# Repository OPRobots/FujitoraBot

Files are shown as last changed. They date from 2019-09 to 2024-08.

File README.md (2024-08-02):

# FujitoraBot
Robot siguelineas MAS RAPIDO DE ESPAÑA!! con motores brushless, succión centrifuga y STM32F4

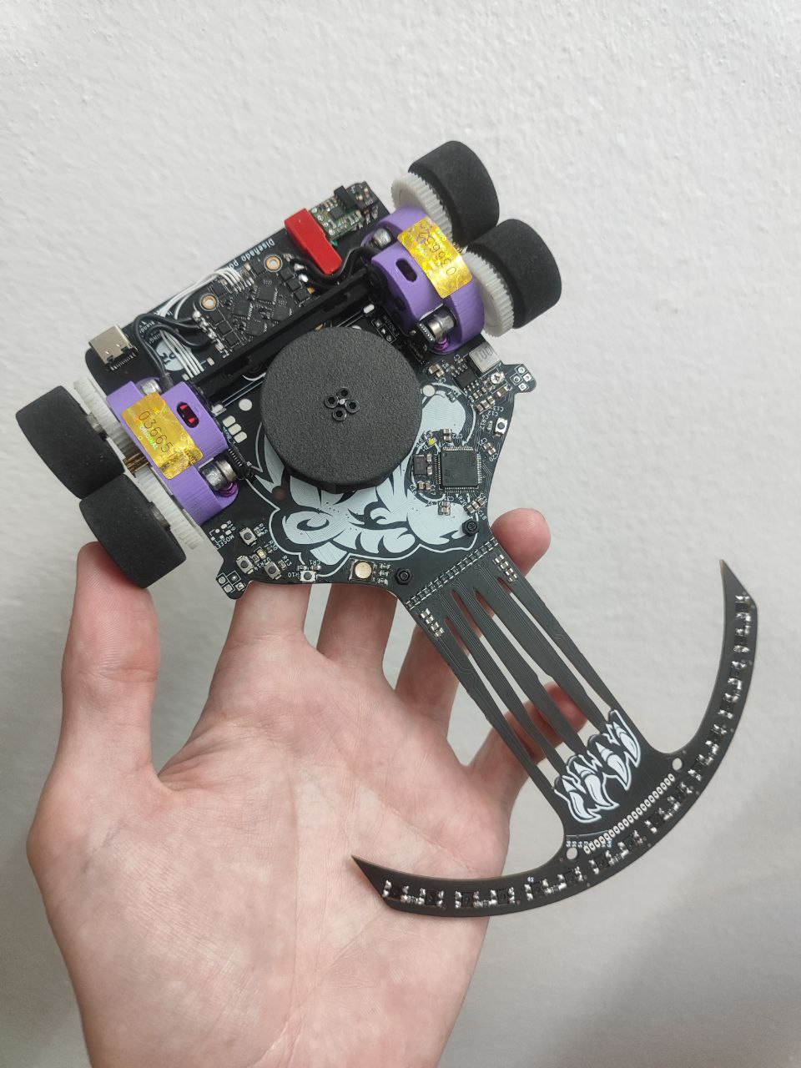
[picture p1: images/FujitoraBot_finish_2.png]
FujitoraBot


## Hardware
- STM32F405RGT6
- ESC 4in1 BlHeli 14A
- 2x Motores Brushless 1306 2700KVs
- 1x Motor brushless 1104 4000KVs (succión)
- DIP Switch 2p SMD
- LiPo 3S 380 mAh
- 16x sensores QRE1113
- Ruedas Scaleauto Procomp 1
- Chasis de PCB con soportes de motores y ventilador en Nylon PA12 SLS

## Software
- Programado con VSCode y PlatformIO con LibOpenCM3
- Disponibles programas de competición

### Versión Robotracer
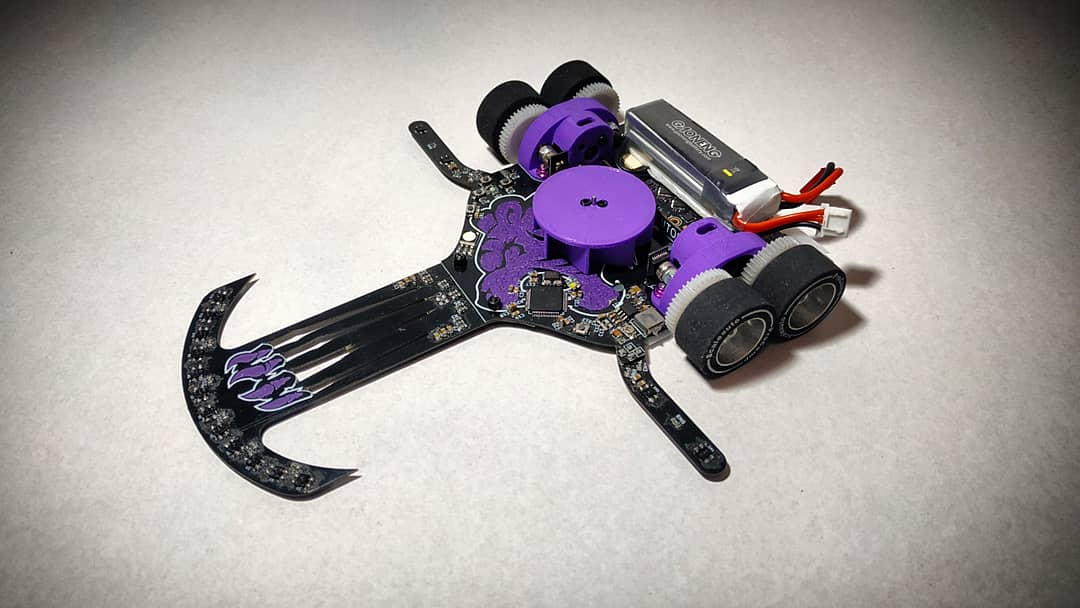
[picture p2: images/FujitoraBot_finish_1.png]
FujitoraBot


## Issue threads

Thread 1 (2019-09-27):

Modos de debug

20leunam, 2019-09-27:
Al seleccionar cada uno de los siguientes modos de debug el led RGB se iluminará con el color correspondiente al modo. Al igual que el menú de velocidad y succión.
- Sensores Raw (cian)
- Sensores calibrados (verde suave)
- Posición de linea (verde)
- Debug motores (amarillo suave)
- Encoders (amarillo)
- Entradas digitales (rojo suave)
- ... (rojo)
- ... (morado suave)
- Fiesta de leds (morado)
- Demostración succión (ultra-instinto)

**Cuando se selecciona un modo de debug se arranca y para con el boton "Start" y fadeará el color correspondiente mientras esté activado. (excepto en "Fiesta de leds" creo)

20leunam, 2019-09-27:
En el tema de analizar si los encoders fallan sería interesante utilizar el index y el numero de pulsos por vuelta para determinar si están dando problemas o no.
En caso de detectar irregularidad en los pulsos de los encoders entre paso y paso del index quizas se podria poner en "alarma" el robot para notificarnoslo, y que pasase automaticamente a de m/s a pwm

robotaleh, 2019-09-28:
> En el tema de analizar si los encoders fallan sería interesante utilizar el index y el numero de pulsos por vuelta para determinar si están dando problemas o no.
> En caso de detectar irregularidad en los pulsos de los encoders entre paso y paso del index quizas se podria poner en "alarma" el robot para notificarnoslo, y que pasase automaticamente a de m/s a pwm

Esto mejor se pasa a un "pending" a parte.

Closed 2019-09-28.

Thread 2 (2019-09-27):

Metodo de selección de modo

20leunam, 2019-09-27:
Con la pulsación por flanco positivo del botón "Enter" se navegará por los siguientes modos:
- Velocidad (parpadeo rápido 50ms)
- Succión (parpadeo medio 200ms)
- Debug (fijo)

** Al cambiar de modo se encenderá el color correspondiente a la configuración que tiene asignada en ese momento durante 250ms

Closed 2019-09-28.

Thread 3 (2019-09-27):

PID a 1ms

20leunam, 2019-09-27:
Cambiar la velocidad de PID a 1ms y que la asignación de velocidad sea inmediatamente despues del calculo del PID, siendo esta, por tanto, asignada también cada 1ms.

**Intentar hacer funcionar los brushless con OneShot 42 (12khz) aunque no coincidan los prescalers

robotaleh, 2019-09-29:
> **Intentar hacer funcionar los brushless con OneShot 42 (12khz) aunque no coincidan los prescalers

Al jugar con los prescalers se consiguen frecuencias de 11,7kHz o 12,6kHz. Con la primera los ESC no se inician y con la segunda arrancan sin control a máxima velocidad; en un futuro si eso se vuelve a intentar.

Closed 2019-09-29.

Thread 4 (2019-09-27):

Sistema de setup

20leunam, 2019-09-27:
Como se deberá comportar el robot en cuanto se encienda:
- Encender robot
- Inicializar timers, relojes, motores, etc.
- Comprobar el estado de los Switches
- Calibrar (en función de los switches calibrará de una u otra forma)
- Atender a los botones de configuración.

robotaleh, 2019-09-29:
Esto ya está listo al atender las issues #1 y #2

Closed 2019-09-29.

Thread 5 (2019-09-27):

The BIG Filtro

20leunam, 2019-09-27:
The BIG Filtro

Realizar un filtro anti saltos sobre la pista que consiste en:
Cuando todos, o la gran mayoría de los sensores valen similar (todos detectando o todos sin detectar) y el último sensor detectando, no es el del extremo correspondiente, mantener el error anterior.

Otra forma de interpretarlo podría ser:
Si la posición del robot es la máxima o la mínima, y la posición anterior no estaba cerca de la máxima o la mínima (según corresponda) mantener la posición anterior.

Closed 2019-09-29.

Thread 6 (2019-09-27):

The BIGGER Filtro

20leunam, 2019-09-27:
The BIGGER Filtro

Realizar un filtro de marcas en el array principal, de tal forma que solo haga caso a la linea central e ignore los sensores que están alejados de la linea dado que se entiende que la información que aporten es irrelevante.

**Teóricamente con este filtro se deberia autoresolverse la issue de: The BIG Filtro

20leunam, 2019-09-27:
Quiero hacer especial hincapié en probar los filtros de manera exhaustiva mediante prints de posición de linea sobre el escritorio, con un folio y cinta aislante, con los motores parados. una vez los prints, el serial ploter y todo diga que funcione, probar en pista. Así se ahorra batería, se aumenta el número de pruebas y se evitan desgracias.

robotaleh, 2019-09-28:
> The BIGGER Filtro
>
> **Teóricamente con este filtro se deberia autoresolverse la issue de: The BIG Filtro

Este filtro es totalmente distinto del #5 ya que este filtra las marcas cuando no hay ningún salto. De hecho, en caso de que todos los sensores estén detectando, este filtro lo que haría sería dejar detectando solo los comprendidos entre la línea anterior.

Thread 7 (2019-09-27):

Codigo de colores en calibración y Tarea Z

20leunam, 2019-09-27:
Código de colores en calibración.

- Si hay 2 o más sensores consecutivos que fallaron la calibración, se pone el led RGB en rojo indicando que hay un fallo de hardware en los sensores que impedirá que el robot corra.
- *Si hay un solo sensor del morro dando fallo, o dos no consecutivos que se puedan ñapear para que intuya la línea, y permita al robot correr, se encenderá el led RGB en Naranja (Esta opción disponible sólo cuando se realice la tarea Z, mientras tanto el RGB a Rojo)
- Si hay un sensor de marca dando fallo de alguno de los dos lados (y estamos en robotracer (?)) encender el led RGB en naranja suave.
- Si hay dos sensores de marcas del mismo lado dando fallo (y estamos en robotracer (?)) encender el led RGB en rojo suave
- En caso de que todos los sensores den valores normales encender el led RGB en verde. (Calibración exitosa)

**En calibración el color suave será un fallo de marchas y el normal un fallo de morro.
***En calibración el color naranja indica que hay un fallo leve y el robot podrá correr igualmente.
****En calibración el color rojo indica un dallo grave, y el robot no podrá correr.

Tarea Z
Última tarea de todas a realizar y menos imprescindible. Cuando todo funcione a la perfección y se tenga un código super estable realizar esta issue:

Ñapear posible sensor de morro con fallo por software, intuyendo que el array está sobre ese sensor si en el medio del array solo detecta un sensor, y ese sensor detectando es uno adyacente al sensor que dió fallo en la calibración.

robotaleh, 2019-09-28:
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

Cuando puedas mueve esto a una issue nueva

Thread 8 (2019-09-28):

Tarea Z

20leunam, 2019-09-28:
Tarea Z
Última tarea de todas a realizar y menos imprescindible. Cuando todo funcione a la perfección y se tenga un código super estable realizar esta issue:

Ñapear posible sensor de morro con fallo por software, intuyendo que el array está sobre ese sensor si en el medio del array solo detecta un sensor, y ese sensor detectando es uno adyacente al sensor que dió fallo en la calibración.

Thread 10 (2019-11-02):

Control de error de encoders

20leunam, 2019-11-02:
Realizar un control en todo momento de la carrera, de que los encoders están funcionando de manera correcta. En caso de detectar un fallo en el numero de pulsos ya sea, que cuenta de menos, o deja de contar, pasar inmediatamente al control de PWM para intentar salvar la carrera.

20leunam, 2019-11-02:
Una posible forma de detectar si los encoders están fallando seria mediante la señal de index de los encoders. En primer lugar medir el numero de pulsos que se cuentan desde un pulso de index hasta el siguiente, ver si el numero de pulsos SIEMPRE es igual, y después, comprobar en carrera cada vez que detecte el pulso de index si pasaron exactamente esos pulsos. En caso de que el numero de pulsos no sea 100% repetitivo, (Lo cual sería preocupante) poner un margen de X ticks de "tolerancia" asimilables. Si no da los pulsos comprendidos entre esa franja de ticks, notificar que encoder esta fallando mediante algún LED y cambiar de m/s a PWM.
En caso de que uno de los encoders deje de funcionar totalmente, tampoco habrá pulso de index, para ello simplemente si no detecto ningún pulso en el ultimo milisegundo* Señalizar que encoder esta en fallo y pasar a PWM

*Previo a esto habría que comprobar cuantos pulsos da a velocidad mínima cada milisegundo, no valla a ser que sea muy poco tiempo como para detectar algún pulso, (Lo cual sería preocupante)

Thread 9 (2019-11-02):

Imprimir sensor en error

20leunam, 2019-11-02:
Después de calibrar sensores de linea, si el led RGB indica un fallo de calibración en algún sensor, imprimir por serial, al pulsar el botón de confirmación de calibración, el numero del sensor o sensores que hayan dado fallo de calibración.

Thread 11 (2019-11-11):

Aceleración inicial en el segundo arranque

20leunam, 2019-11-11:
Realizar una aceleración inicial siempre que se arranque el robot. Incluido cuando se arranca el robot nuevamente, después de haberse parado por pérdida linea.

robotaleh, 2019-11-11:
Parece ser que las variables que controlan la aceleración inicial no se están reseteando cuando el robot se para por pérdida de línea

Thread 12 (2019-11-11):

Guardar valores de calibración en la "EEPROM"

20leunam, 2019-11-11:
Una vez realizada una calibración exitosa, y comprobada la fiabilidad del robot con esa calibración, guardar los valores calibrados en una EEPROM emulada, usando la memoria flash del STM32F4.
Info de interes:
https://github.com/Bulebots/bulebule/issues/239

20leunam, 2019-11-11:
Esto cambia bastante el protocolo de inicialización del robot de la issue https://github.com/OPRobots/FujitoraBot/issues/4
Por ello es necesario un replanteamiento del sistema de funcionamiento para cuando tenga calibración guardada, para cuando no, para poder borrarla, y para poder guardarla.
Hago una primera propuesta:

1. Sin calibración guardada (Switch, modo debug)

- Encender robot
- Inicializar timers, relojes, motores, etc.
- Comprobar el estado de los Switches
- Calibrar moviendo el robot.
- Durante la calibración comprueba que los encoders hayan dado algún valor
- Atender a los botones de configuración.
- Probar el robot en pista, dar unas cuantas vueltas y estresarlo, intentando probocar el fallo para determinar que esa calibración funciona bien
- Ir al modo debug y tener una nueva opción de guardado de calibración.

2. Con calibración guardada (Switch,  modo debug)

- Encender robot
- Inicializar timers, relojes, motores, etc.
- Comprobar el estado de los Switches
- Si encendiste el robot con el botón de Start pulsado, significa que quieres sobreescribir la calibración. Entonces, saltar el siguiente punto. Si no, saltar este punto.
- Si no hay calibración guardada dar alarma... (RGB rojo, parpadeando rápido) si la hay continuar como si nada.
- Pulsar botón de start, Arrancar durante 250ms los motores de tracción para comprobar el funcionamiento de los encoders, y volver a pulsar start para confirmar la comprobación
- Atender a los botones de configuración.
- Probar el robot en pista, dar unas cuantas vueltas y estresarlo, intentando provocar el fallo para determinar que esa calibración funciona bien
- Ir al modo debug y tener una nueva opción de guardado de calibración.

3. Con calibración guardada (Switch, modo competición)

- Encender robot
- Inicializar timers, relojes, motores, etc.
- Comprobar el estado de los Switches
- Si no hay calibración guardada dar alarma... (RGB rojo, parpadeando rápido) si la hay continuar como si nada.
- Pulsar botón de start, Arrancar durante 250ms los motores de tracción para comprobar el funcionamiento de los encoders, y volver a pulsar start para confirmar la comprobación
- Atender a los botones de configuración.
- Probar el robot en pista, dar unas cuantas vueltas y estresarlo, intentando provocar el fallo para determinar que esa calibración funciona bien
- Ir al modo debug y tener una nueva opción de guardado de calibración.

robotaleh, 2019-11-11:
Al margen de iniciar los motores de tracción durante 250ms para comprobar encoders, lo cual veo bien, creo que todo el proceso de guardado, borrado, ... de calibración es demasiado tedioso tanto para debug como para competición. Mi contra-propuesta es la siguiente:

- Cada vez que se calibre el robot, se guarda y sobrescribe automáticamente los valores de calibración anteriores, estés en el switch que estés.

- Al iniciar el programa, se comprueba si existe una calibración guardada y en caso de que así sea se encenderá el RGB directamente en Verde para confirmar la calibración. En caso de que se quiera descartar esa calibración, se deberá pulsar durante 1-2s el botón de confirmación iniciando de nuevo el proceso de calibración y posterior guardado de esos datos.

De esta forma se simplificaría la lógica de switches y se conserva la posibilidad de sobrescribir lo guardado.

20leunam, 2019-11-11:
Okay, me parece más simple. Por buscarle un poco las cosquillas...
"Al iniciar el programa, se comprueba si existe una calibración guardada y en caso de que así sea se encenderá el RGB directamente en Verde" dado que guarda automáticamente todas las calibraciones, si una calibración no sale bien, al encender el robot mostrará el color del estado de la calibración guardada, no siempre verde.

20leunam, 2019-11-11:
Dandole mas vueltas al sistema, resulta que asi se pierde la comprobación de que los sensores de línea están funcionando correctamente al dejar de hacer la calibración. Por ello abro una nueva issue para tratar este tema en concreto.

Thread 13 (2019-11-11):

Comprobación de "Robot vivo" antes de arrancar

20leunam, 2019-11-11:
Antes de cualquier carrera ya sea de pruebas o de competición es interesante hacer una pequeña comprobación de que los elementos críticos del robot están funcionando correctamente, y así evitar que se salga nada más arrancar si hay algo que no está funcionando como debe. Estos temas se tratan en las issues: #7 y #10
Las pruebas que se deben hacer antes de arrancar son, comprobar que todos los sensores leen (básicamente que no hay ninguno roto) y que los encoders están dando bien los pulsos.
Para realizar estas pruebas de manera compatible con la calibración y el grabado de calibración en EEPROM de la issue #12 se pensó hacerlo de la siguiente forma:

Al encender el robot tenga o no guardada calibración parpadeará el led RGB en dos colores diferentes, por ejemplo rojo(Sensores) y morado(encoders) alternándose entre ellos. En cuanto todos los sensores detecten una variación de valor definida, por ejemplo 200 unidades del ADC (de 0 a 4000). el led rojo dejará de estar parpadeando y quedará parpadeando el morado solo. En cuanto las ruedas den una vuelta y se lean los pulsos adecuados, se apagará el led RGB y se dará por finalizadas las pruebas de "Robot vivo". (Si antes de que se comprueben los sensores se mueven las ruedas y se verifican los encoders, se quedaría el rojo parpadeando solo).

A continuación habrá una espera de unos 250ms y continuará con el protocolo de la calibración redefinido en la issue #12

20leunam, 2019-11-11:
Si los Switches están en modo PWM, significa que hay un fallo de los encoders, y se va a arriesgar a correr a pelo, entonces el led morado ya no encendería para permitir correr en cuanto los sensores digan que estan bien. Y si es para correr en robotracer, significa que va a ingnorar todas las marcas de izquierdas, y va a correr a ciegas solo para completar, y no retirarse solo por un encoder.

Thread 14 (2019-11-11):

Mapeo de pista de Robotracer

robotaleh, 2019-11-11:
Es necesario mapear correctamente la pista de robotracer usando los sensores de marcas y los encoders de forma que sea posible acelerar en las rectas y curvas amplias.

El método inicial de memorización será el siguiente:

- Se monitorizará cada cierto tiempo la velocidad lineal y angular del robot para realizar un cálculo promedio del radio de curvatura del sector actual. Con ese radio, posteriormente, se establecerá la velocidad máxima del robot en ese sector. Por ejemplo, se podrían definir velocidades para R>10, R>20, R>30 y R>40 y establecerlas en consecuencia en el momento de resolver el circuito.

- Sensor marcas derecho: Comprueba si no se ha iniciado la vuelta e inicia el mapeo, o lo finaliza en caso contrario. Igual en el caso de resolución.
- Sensor marcas izquierdo: Su labor es consolidar los sectores terminados y resetear el conteo de ticks de los encoders para el nuevo sector, además de asignar a cada sector su radio medio calculado anteriormente y limpiar el registro promedio de radios.

En ambos sensores, para evitar lecturas erróneas, se debería hacer una comprobación de que el sensor esté detectando durante un cierto tiempo o cierta cantidad de ticks para no consolidar sectores incorrectamente.

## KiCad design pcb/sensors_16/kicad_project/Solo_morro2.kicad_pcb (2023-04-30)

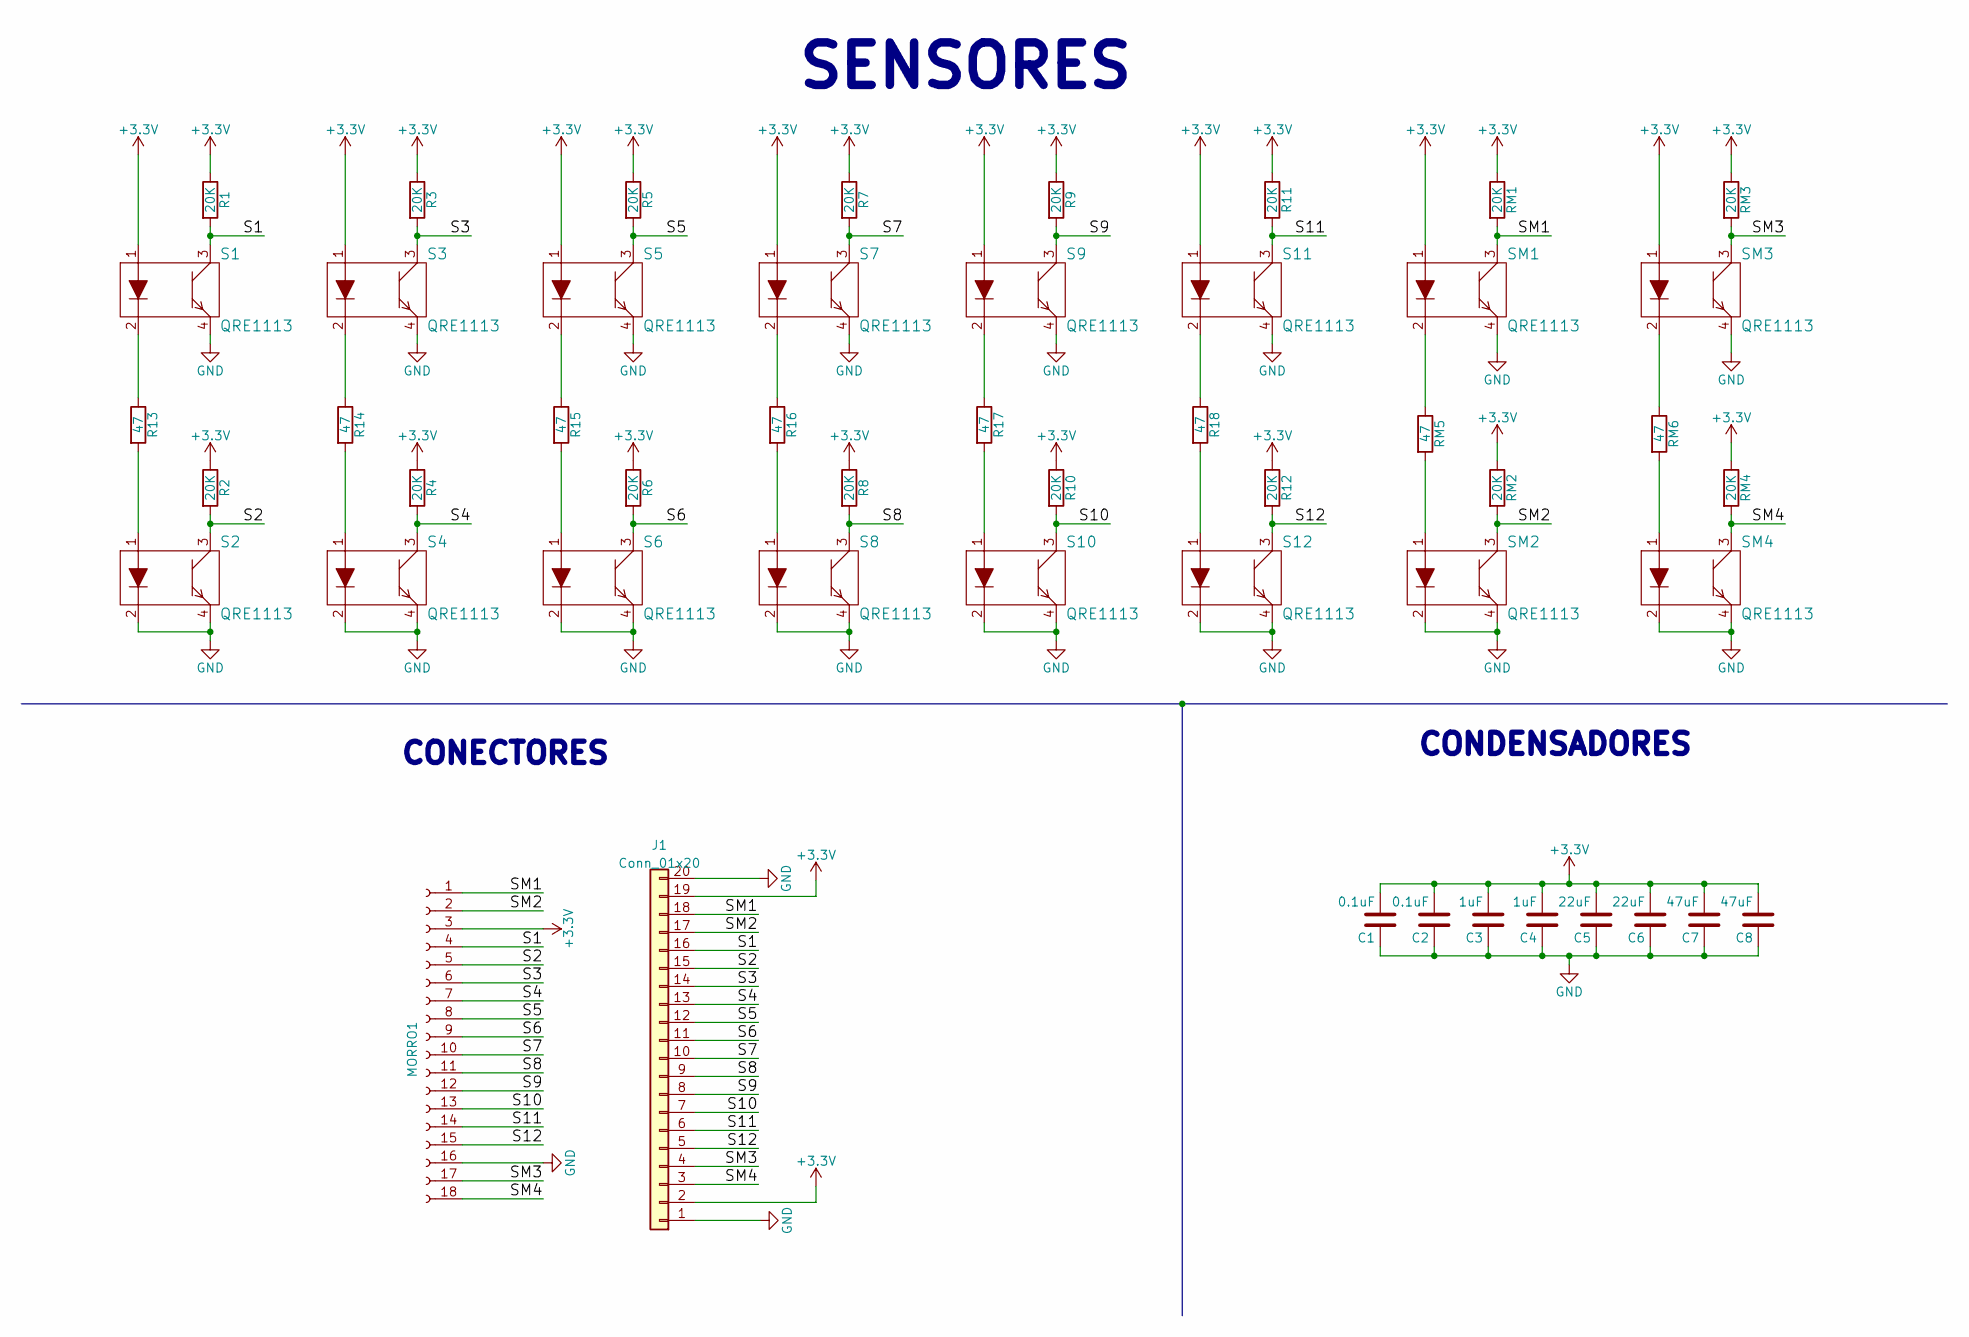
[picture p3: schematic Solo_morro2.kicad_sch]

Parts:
C1, C2: 0.1uF; C_0805_2012Metric
C3, C4: 1uF; C_0805_2012Metric
C5, C6: 22uF; C_0805_2012Metric
C7, C8: 47uF; C_0805_2012Metric
J1: Conn_01x20; Pines_fuji_morro2
MORRO1: Conn_01x14_Female; conn_morro_fuji_new
R1, R2, R3, R4, R5, R6, R7, R8, R9, R10, R11, R12: 20K; R_0805_2012Metric
R13, R14, R15, R16, R17, R18: 47; R_0805_2012Metric
RM1, RM2, RM3, RM4: 20K; R_0805_2012Metric
RM5, RM6: 47; R_0805_2012Metric
S1, S2, S3, S4, S5, S6, S7, S8, S9, S10, S11, S12: QRE1113; qre1113_fuji_morro2
SM1, SM2, SM3, SM4: QRE1113; qre1113_fuji_morro2

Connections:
+3V3: C1.2, C2.2, C3.2, C4.2, C5.2, C6.2, C7.2, C8.2, J1.2, J1.19, MORRO1.3, R1.1, R2.1, R3.1, R4.1, R5.1, R6.1, R7.1, R8.1, R9.1, R10.1, R11.1, R12.1, RM1.1, RM2.1, RM3.1, RM4.1, S1.1, S3.1, S5.1, S7.1, S9.1, S11.1, SM1.1, SM3.1
/S1: J1.16, MORRO1.4, R1.2, S1.3
/S2: J1.15, MORRO1.5, R2.2, S2.3
/S3: J1.14, MORRO1.6, R3.2, S3.3
/S4: J1.13, MORRO1.7, R4.2, S4.3
/S5: J1.12, MORRO1.8, R5.2, S5.3
/S6: J1.11, MORRO1.9, R6.2, S6.3
/S7: J1.10, MORRO1.10, R7.2, S7.3
/S8: J1.9, MORRO1.11, R8.2, S8.3
/S9: J1.8, MORRO1.12, R9.2, S9.3
/S10: J1.7, MORRO1.13, R10.2, S10.3
/S11: J1.6, MORRO1.14, R11.2, S11.3
/S12: J1.5, MORRO1.15, R12.2, S12.3
/SM1: J1.18, MORRO1.1, RM1.2, SM1.3
/SM2: J1.17, MORRO1.2, RM2.2, SM2.3
/SM3: J1.4, MORRO1.17, RM3.2, SM3.3
/SM4: J1.3, MORRO1.18, RM4.2, SM4.3
GND: C1.1, C2.1, C3.1, C4.1, C5.1, C6.1, C7.1, C8.1, J1.1, J1.20, MORRO1.16, S1.4, S2.2, S2.4, S3.4, S4.2, S4.4, S5.4, S6.2, S6.4, S7.4, S8.2, S8.4, S9.4, S10.2, S10.4, S11.4, S12.2, S12.4, SM1.4, SM2.2, SM2.4, SM3.4, SM4.2, SM4.4
unnamed: R13.1, S1.2
unnamed: R13.2, S2.1
unnamed: R14.1, S3.2
unnamed: R14.2, S4.1
unnamed: R15.1, S5.2
unnamed: R15.2, S6.1
unnamed: R16.1, S7.2
unnamed: R16.2, S8.1
unnamed: R17.1, S9.2
unnamed: R17.2, S10.1
unnamed: R18.1, S11.2
unnamed: R18.2, S12.1
unnamed: RM5.1, SM1.2
unnamed: RM5.2, SM2.1
unnamed: RM6.1, SM3.2
unnamed: RM6.2, SM4.1

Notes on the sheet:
SENSORES
CONECTORES
CONDENSADORES

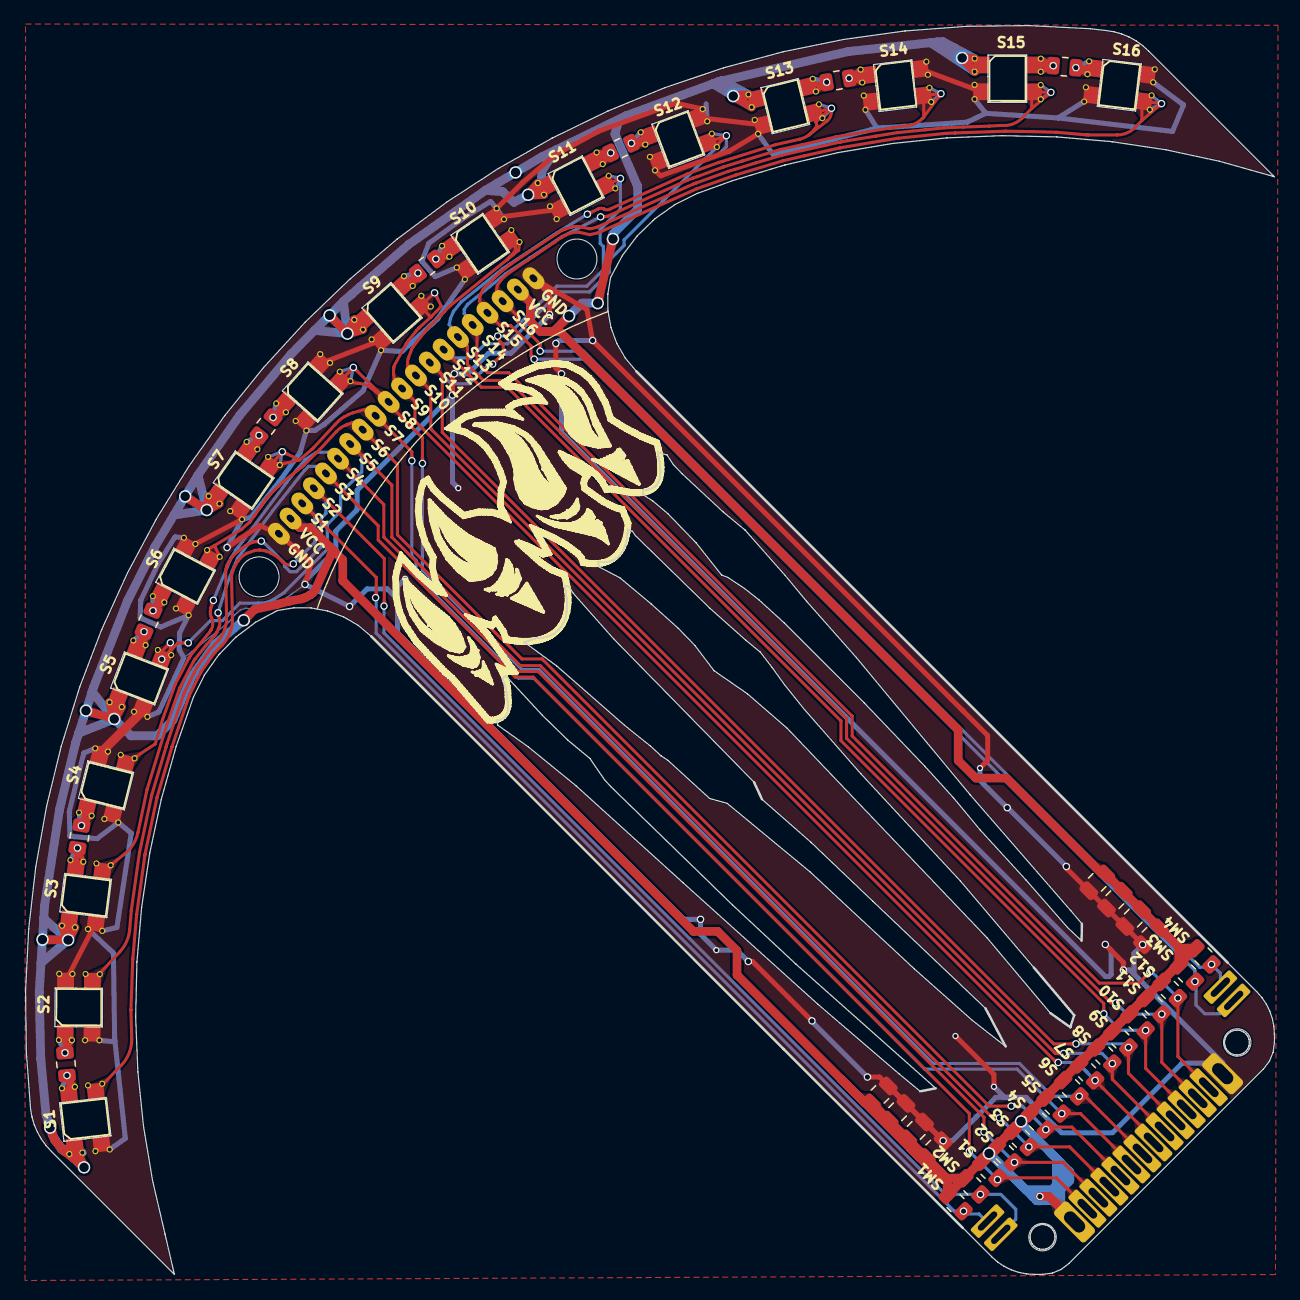
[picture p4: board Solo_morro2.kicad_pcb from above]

Board: 2 copper layers, 100.0 x 100.0 mm, 50 parts (1 on the bottom side), 34 nets.

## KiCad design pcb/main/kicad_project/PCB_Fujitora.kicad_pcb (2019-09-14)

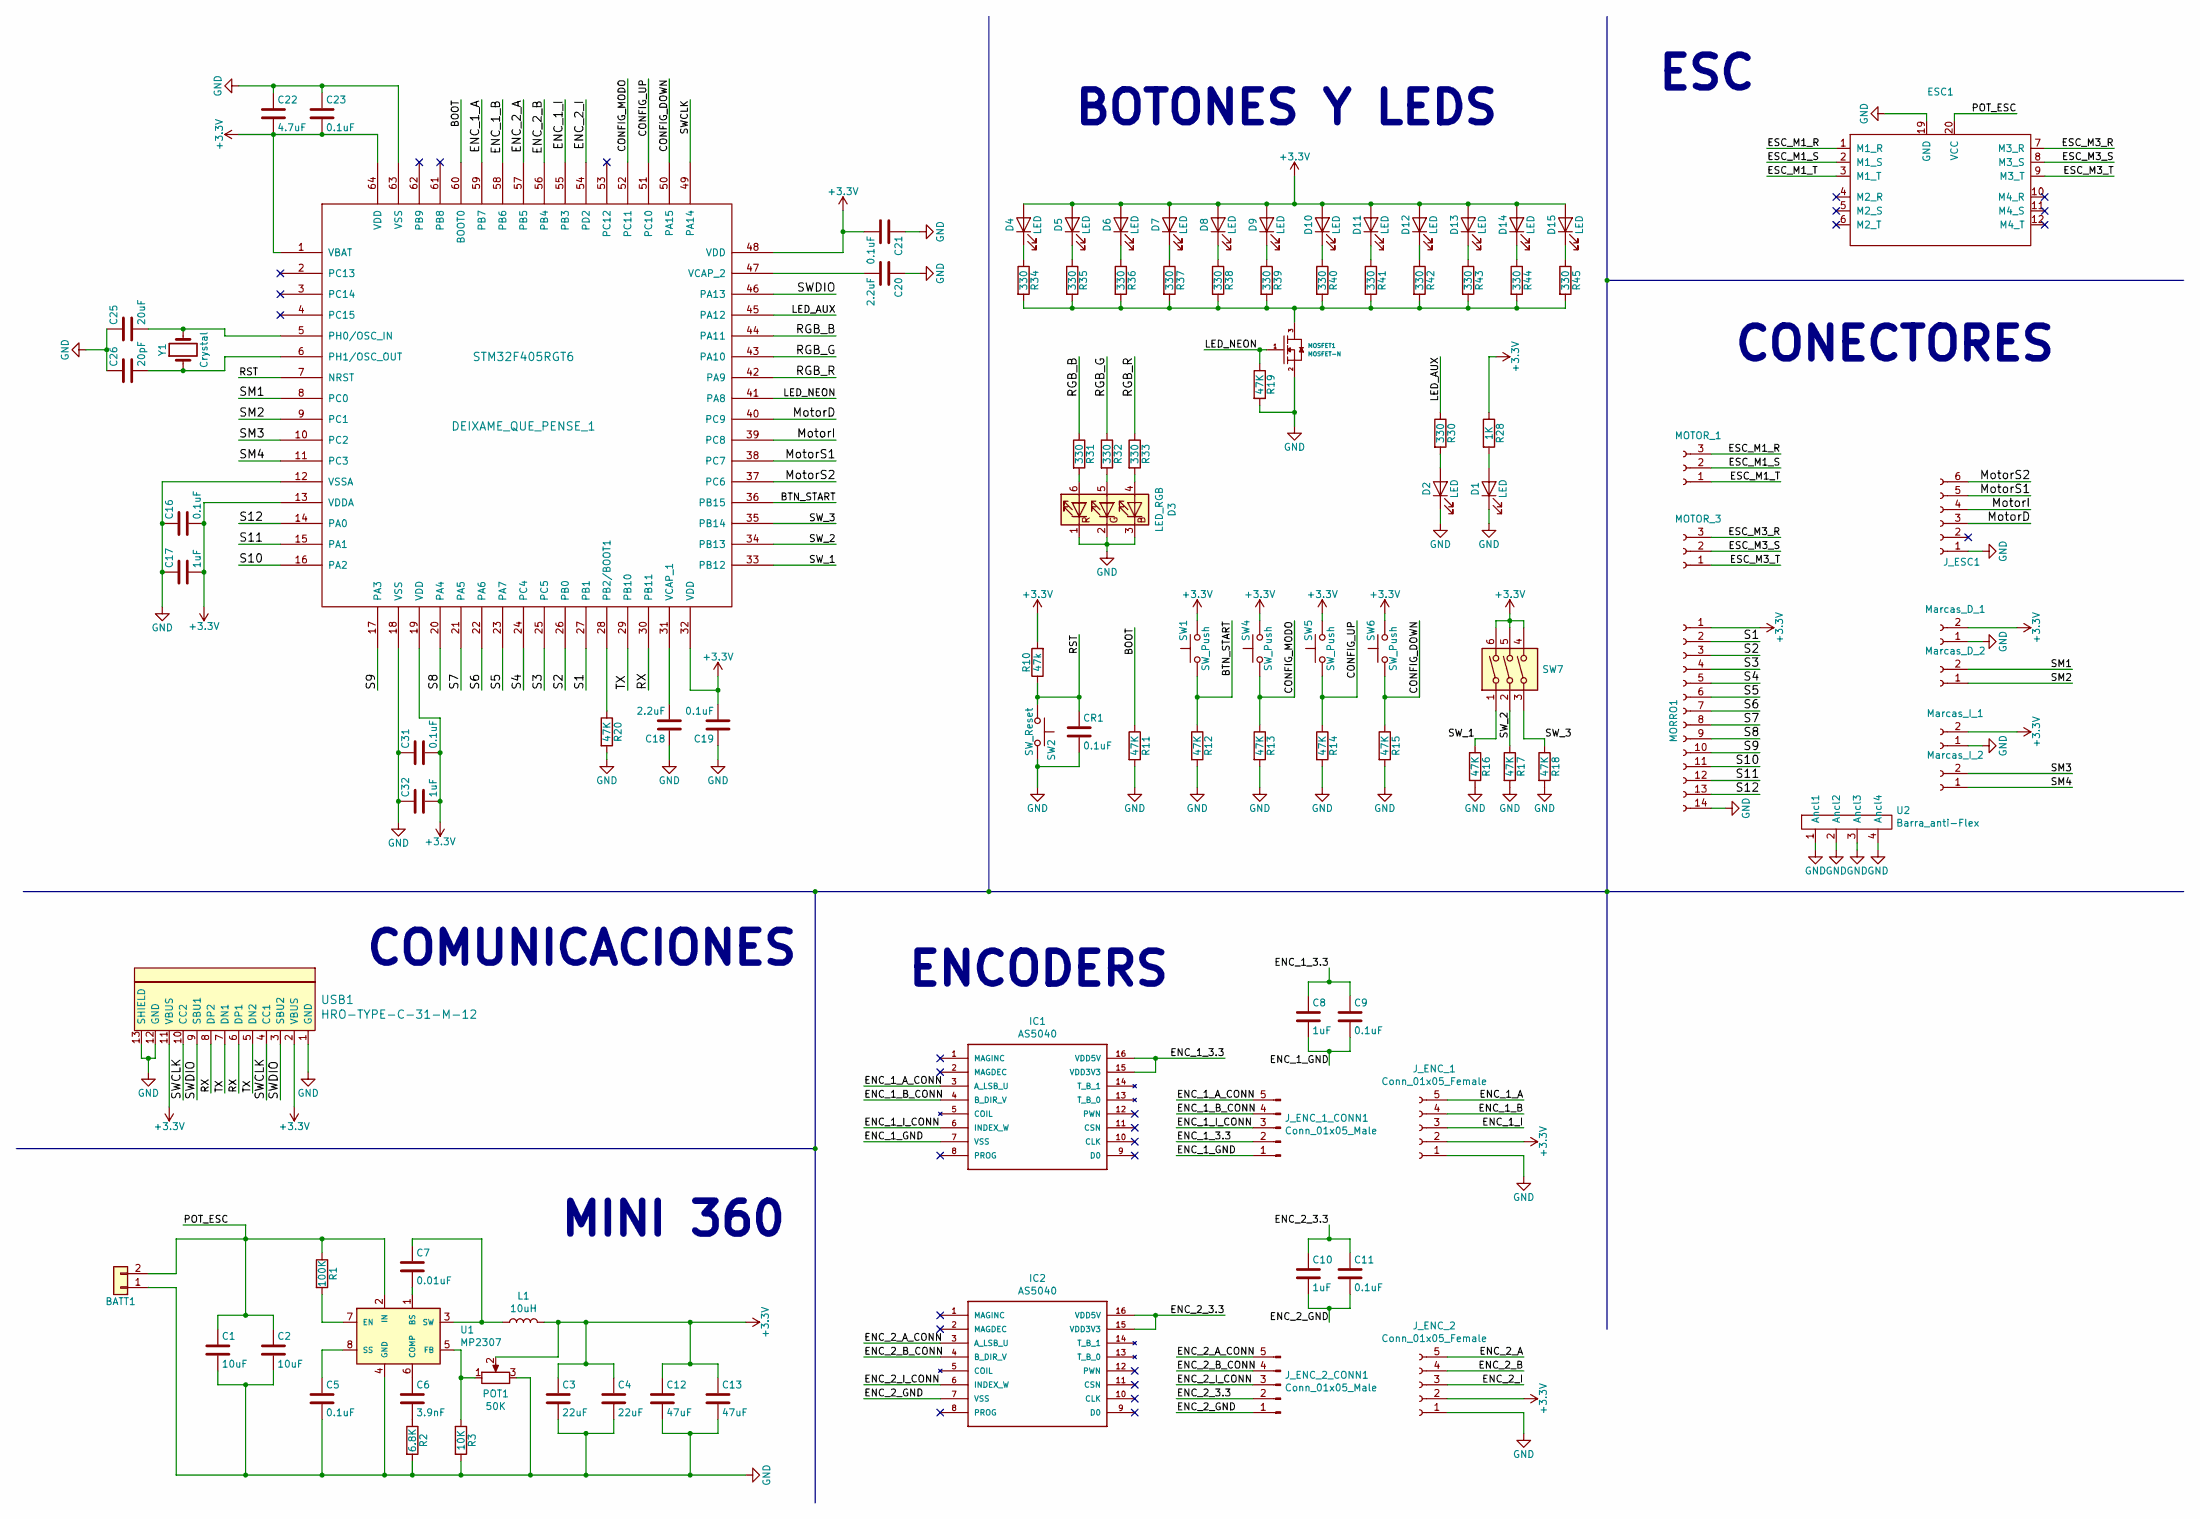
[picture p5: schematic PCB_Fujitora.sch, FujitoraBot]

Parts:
BATT1: Conn_01x02; PinHeader_1x02_P2.54mm_Vertical
C1: 10uF; C_1206_3216Metric
C2: 10uF; C_0805_2012Metric
C3: 22uF; C_1206_3216Metric
C4: 22uF; C_0805_2012Metric
C5: 0.1uF; C_0603_1608Metric
C6: 3.9nF; C_0603_1608Metric
C7: 0.01uF; C_0603_1608Metric
C8, C10, C17, C32: 1uF; C_0805_2012Metric
C9, C11, C16, C19, C21, C23, C31: 0.1uF; C_0805_2012Metric
C12, C13: 47uF; C_0805_2012Metric
C18, C20: 2.2uF; C_0805_2012Metric
C22: 4.7uF; C_0805_2012Metric
C25: 20uF; C_0805_2012Metric
C26: 20pF; C_0805_2012Metric
CR1: 0.1uF; C_0805_2012Metric
D1, D2, D4, D5, D6, D7, D8, D9, D10, D11, D12, D13, D14, D15: LED; LED_0805_2012Metric
D3: LED_RGB; LED_RGB_5050-6
DEIXAME_QUE_PENSE_1: STM32F405RGT6; LQFP-64_10x10mm_P0.5mm
ESC1: ESC_x4_15A
IC1, IC2: AS5040; SSOP-16_5.3x6.2mm_P0.65mm
J_ENC_1, J_ENC_2: Conn_01x05_Female; PinHeader_1x05_P1.27mm_Vertical
J_ENC_1_CONN1, J_ENC_2_CONN1: Conn_01x05_Male; PinHeader_1x05_P1.27mm_Vertical
J_ESC1: Conn_01x06_Female; JST_SH_SM06B-SRSS-TB_1x06-1MP_P1.00mm_Horizontal
L1: 10uH; L_Wuerth_HCM-7050
MORRO1: Conn_01x14_Female; conn_morro_fuji_new
MOSFET1: MOSFET-N; SOT-23
MOTOR_1: Conn_01x03_Female; PinHeader_1x03_P2.54mm_Vertical
MOTOR_3: Conn_01x03_Female; Conn_SMDx3_2.54
Marcas_D_1, Marcas_D_2: Conn_01x02_Female; PinHeader_1x02_P2.54mm_Vertical
Marcas_I_1, Marcas_I_2: Conn_01x02_Female; PinHeader_1x02_P2.54mm_Vertical
POT1: 50K; Potentiometer_Vishay_TS53YJ_Vertical
R1: 100K; R_0603_1608Metric
R2: 6.8K; R_0603_1608Metric
R3: 10K; R_0603_1608Metric
R10: 47k; R_0805_2012Metric
R11, R12, R13, R14, R15, R16, R17, R18, R19, R20: 47K; R_0805_2012Metric
R28: 1K; R_0805_2012Metric
R30, R31, R32, R33, R34, R35, R36, R37, R38, R39, R40, R41, R42, R43, R44, R45: 330; R_0805_2012Metric
SW1, SW4, SW5, SW6: SW_Push; SW_SPST_B3U-1000P
SW2: SW_Reset; SW_SPST_B3U-1000P
SW7: SW_DIP_x03; SW_DIP_SPSTx03_Slide_6.7x9.18mm_W8.61mm_P2.54mm_LowProfile
U1: MP2307; SOIC-8-1EP_3.9x4.9mm_P1.27mm_EP2.35x2.35mm
U2: Barra_anti-Flex; Barra_Anti-Flex
USB1: HRO-TYPE-C-31-M-12
Y1: Crystal; Crystal_SMD_5032-2Pin_5.0x3.2mm

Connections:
+3V3: C3.1, C4.1, C12.1, C13.1, C16.2, C17.2, C19.2, C21.2, C22.2, C23.2, C31.2, C32.2, D4.2 (A), D5.2 (A), D6.2 (A), D7.2 (A), D8.2 (A), D9.2 (A), D10.2 (A), D11.2 (A), D12.2 (A), D13.2 (A), D14.2 (A), D15.2 (A), DEIXAME_QUE_PENSE_1.1 (VBAT), DEIXAME_QUE_PENSE_1.13 (VDDA), DEIXAME_QUE_PENSE_1.19 (VDD), DEIXAME_QUE_PENSE_1.32 (VDD), DEIXAME_QUE_PENSE_1.48 (VDD), DEIXAME_QUE_PENSE_1.64 (VDD), J_ENC_1.2, J_ENC_2.2, L1.2, MORRO1.1, Marcas_D_1.2, Marcas_I_1.2, POT1.2, R10.2, R28.1, SW1.2, SW4.2, SW5.2, SW6.2, SW7.4, SW7.5, SW7.6, USB1.2 (VBUS), USB1.11 (VBUS)
/BOOT: DEIXAME_QUE_PENSE_1.60 (BOOT0), R11.1
/BTN_START: DEIXAME_QUE_PENSE_1.36 (PB15), R12.1, SW1.1
/CONFIG_DOWN: DEIXAME_QUE_PENSE_1.50 (PA15), R15.1, SW6.1
/CONFIG_MODO: DEIXAME_QUE_PENSE_1.52 (PC11), R13.1, SW4.1
/CONFIG_UP: DEIXAME_QUE_PENSE_1.51 (PC10), R14.1, SW5.1
/ENC_1_3.3: C8.1, C9.1, IC1.15 (VDD3V3), IC1.16 (VDD5V), J_ENC_1_CONN1.2
/ENC_1_A: DEIXAME_QUE_PENSE_1.59 (PB7), J_ENC_1.5
/ENC_1_A_CONN: IC1.3 (A_LSB_U), J_ENC_1_CONN1.5
/ENC_1_B: DEIXAME_QUE_PENSE_1.58 (PB6), J_ENC_1.4
/ENC_1_B_CONN: IC1.4 (B_DIR_V), J_ENC_1_CONN1.4
/ENC_1_GND: C8.2, C9.2, IC1.7 (VSS), J_ENC_1_CONN1.1
/ENC_1_I: DEIXAME_QUE_PENSE_1.55 (PB3), J_ENC_1.3
/ENC_1_I_CONN: IC1.6 (INDEX_W), J_ENC_1_CONN1.3
/ENC_2_3.3: C10.1, C11.1, IC2.15 (VDD3V3), IC2.16 (VDD5V), J_ENC_2_CONN1.2
/ENC_2_A: DEIXAME_QUE_PENSE_1.57 (PB5), J_ENC_2.5
/ENC_2_A_CONN: IC2.3 (A_LSB_U), J_ENC_2_CONN1.5
/ENC_2_B: DEIXAME_QUE_PENSE_1.56 (PB4), J_ENC_2.4
/ENC_2_B_CONN: IC2.4 (B_DIR_V), J_ENC_2_CONN1.4
/ENC_2_GND: C10.2, C11.2, IC2.7 (VSS), J_ENC_2_CONN1.1
/ENC_2_I: DEIXAME_QUE_PENSE_1.54 (PD2), J_ENC_2.3
/ENC_2_I_CONN: IC2.6 (INDEX_W), J_ENC_2_CONN1.3
/ESC_M1_R: ESC1.1 (M1_R), MOTOR_1.3
/ESC_M1_S: ESC1.2 (M1_S), MOTOR_1.2
/ESC_M1_T: ESC1.3 (M1_T), MOTOR_1.1
/ESC_M3_R: ESC1.7 (M3_R), MOTOR_3.3
/ESC_M3_S: ESC1.8 (M3_S), MOTOR_3.2
/ESC_M3_T: ESC1.9 (M3_T), MOTOR_3.1
/LED_AUX: DEIXAME_QUE_PENSE_1.45 (PA12), R30.1
/LED_NEON: DEIXAME_QUE_PENSE_1.41 (PA8), MOSFET1.1, R19.1
/MotorD: DEIXAME_QUE_PENSE_1.40 (PC9), J_ESC1.3
/MotorI: DEIXAME_QUE_PENSE_1.39 (PC8), J_ESC1.4
/MotorS1: DEIXAME_QUE_PENSE_1.38 (PC7), J_ESC1.5
/MotorS2: DEIXAME_QUE_PENSE_1.37 (PC6), J_ESC1.6
/POT_ESC: BATT1.2, C1.1, C2.1, ESC1.20 (VCC), R1.1, U1.2 (IN)
/RGB_B: DEIXAME_QUE_PENSE_1.44 (PA11), R31.1
/RGB_G: DEIXAME_QUE_PENSE_1.43 (PA10), R32.1
/RGB_R: DEIXAME_QUE_PENSE_1.42 (PA9), R33.1
/RST: CR1.1, DEIXAME_QUE_PENSE_1.7 (NRST), R10.1, SW2.1
/RX: DEIXAME_QUE_PENSE_1.30 (PB11), USB1.6 (DP1), USB1.8 (DP2)
/S1: DEIXAME_QUE_PENSE_1.27 (PB1), MORRO1.2
/S2: DEIXAME_QUE_PENSE_1.26 (PB0), MORRO1.3
/S3: DEIXAME_QUE_PENSE_1.25 (PC5), MORRO1.4
/S4: DEIXAME_QUE_PENSE_1.24 (PC4), MORRO1.5
/S5: DEIXAME_QUE_PENSE_1.23 (PA7), MORRO1.6
/S6: DEIXAME_QUE_PENSE_1.22 (PA6), MORRO1.7
/S7: DEIXAME_QUE_PENSE_1.21 (PA5), MORRO1.8
/S8: DEIXAME_QUE_PENSE_1.20 (PA4), MORRO1.9
/S9: DEIXAME_QUE_PENSE_1.17 (PA3), MORRO1.10
/S10: DEIXAME_QUE_PENSE_1.16 (PA2), MORRO1.11
/S11: DEIXAME_QUE_PENSE_1.15 (PA1), MORRO1.12
/S12: DEIXAME_QUE_PENSE_1.14 (PA0), MORRO1.13
/SM1: DEIXAME_QUE_PENSE_1.8 (PC0), Marcas_D_2.2
/SM2: DEIXAME_QUE_PENSE_1.9 (PC1), Marcas_D_2.1
/SM3: DEIXAME_QUE_PENSE_1.10 (PC2), Marcas_I_2.2
/SM4: DEIXAME_QUE_PENSE_1.11 (PC3), Marcas_I_2.1
/SWCLK: DEIXAME_QUE_PENSE_1.49 (PA14), USB1.4 (CC1), USB1.10 (CC2)
/SWDIO: DEIXAME_QUE_PENSE_1.46 (PA13), USB1.3 (SBU2), USB1.9 (SBU1)
/SW_1: DEIXAME_QUE_PENSE_1.33 (PB12), R16.1, SW7.1
/SW_2: DEIXAME_QUE_PENSE_1.34 (PB13), R17.1, SW7.2
/SW_3: DEIXAME_QUE_PENSE_1.35 (PB14), R18.1, SW7.3
/TX: DEIXAME_QUE_PENSE_1.29 (PB10), USB1.5 (DN2), USB1.7 (DN1)
GND: BATT1.1, C1.2, C2.2, C3.2, C4.2, C5.2, C12.2, C13.2, C16.1, C17.1, C18.1, C19.1, C20.1, C21.1, C22.1, C23.1, C25.1, C26.1, C31.1, C32.1, CR1.2, D1.1 (K), D2.1 (K), D3.1 (RK), D3.2 (GK), D3.3 (BK), DEIXAME_QUE_PENSE_1.12 (VSSA), DEIXAME_QUE_PENSE_1.18 (VSS), DEIXAME_QUE_PENSE_1.63 (VSS), ESC1.19 (GND), J_ENC_1.1, J_ENC_2.1, J_ESC1.1, MORRO1.14, MOSFET1.2, Marcas_D_1.1, Marcas_I_1.1, POT1.3, R2.2, R3.2, R11.2, R12.2, R13.2, R14.2, R15.2, R16.2, R17.2, R18.2, R19.2, R20.2, SW2.2, U1.4 (GND), U2.1 (Ancl1), U2.2 (Ancl2), U2.3 (Ancl3), U2.4 (Ancl4), USB1.1 (GND), USB1.12 (GND), USB1.13 (SHIELD)
unnamed: C5.1, U1.8 (SS)
unnamed: C6.1, U1.6 (COMP)
unnamed: C6.2, R2.1
unnamed: C7.1, L1.1, U1.3 (SW)
unnamed: C7.2, U1.1 (BS)
unnamed: C18.2, DEIXAME_QUE_PENSE_1.31 (VCAP_1)
unnamed: C20.2, DEIXAME_QUE_PENSE_1.47 (VCAP_2)
unnamed: C25.2, DEIXAME_QUE_PENSE_1.5 (PH0/OSC_IN), Y1.2
unnamed: C26.2, DEIXAME_QUE_PENSE_1.6 (PH1/OSC_OUT), Y1.1
unnamed: D1.2 (A), R28.2
unnamed: D2.2 (A), R30.2
unnamed: D3.4 (BA), R33.2
unnamed: D3.5 (GA), R32.2
unnamed: D3.6 (RA), R31.2
unnamed: D4.1 (K), R34.1
unnamed: D5.1 (K), R35.1
unnamed: D6.1 (K), R36.1
unnamed: D7.1 (K), R37.1
unnamed: D8.1 (K), R38.1
unnamed: D9.1 (K), R39.1
unnamed: D10.1 (K), R40.1
unnamed: D11.1 (K), R41.1
unnamed: D12.1 (K), R42.1
unnamed: D13.1 (K), R43.1
unnamed: D14.1 (K), R44.1
unnamed: D15.1 (K), R45.1
unnamed: DEIXAME_QUE_PENSE_1.28 (PB2/BOOT1), R20.1
unnamed: MOSFET1.3, R34.2, R35.2, R36.2, R37.2, R38.2, R39.2, R40.2, R41.2, R42.2, R43.2, R44.2, R45.2
unnamed: POT1.1, R3.1, U1.5 (FB)
unnamed: R1.2, U1.7 (EN)

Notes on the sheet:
MINI 360
ENCODERS
BOTONES Y LEDS
CONECTORES
ESC
COMUNICACIONES

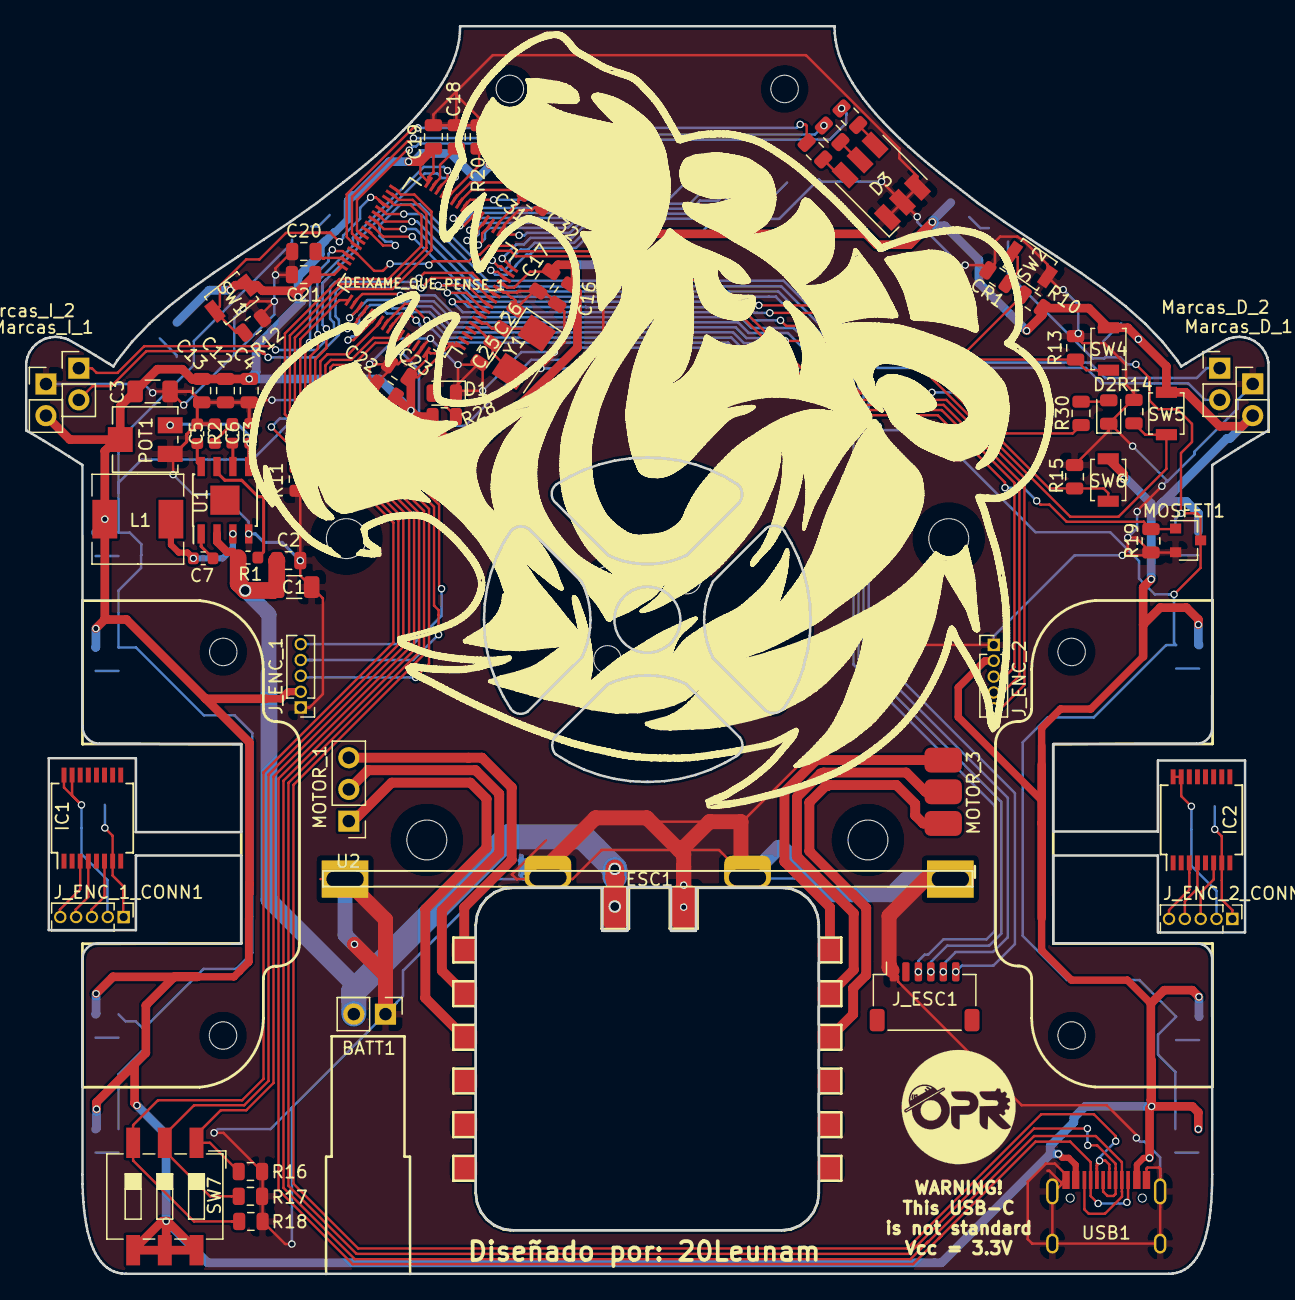
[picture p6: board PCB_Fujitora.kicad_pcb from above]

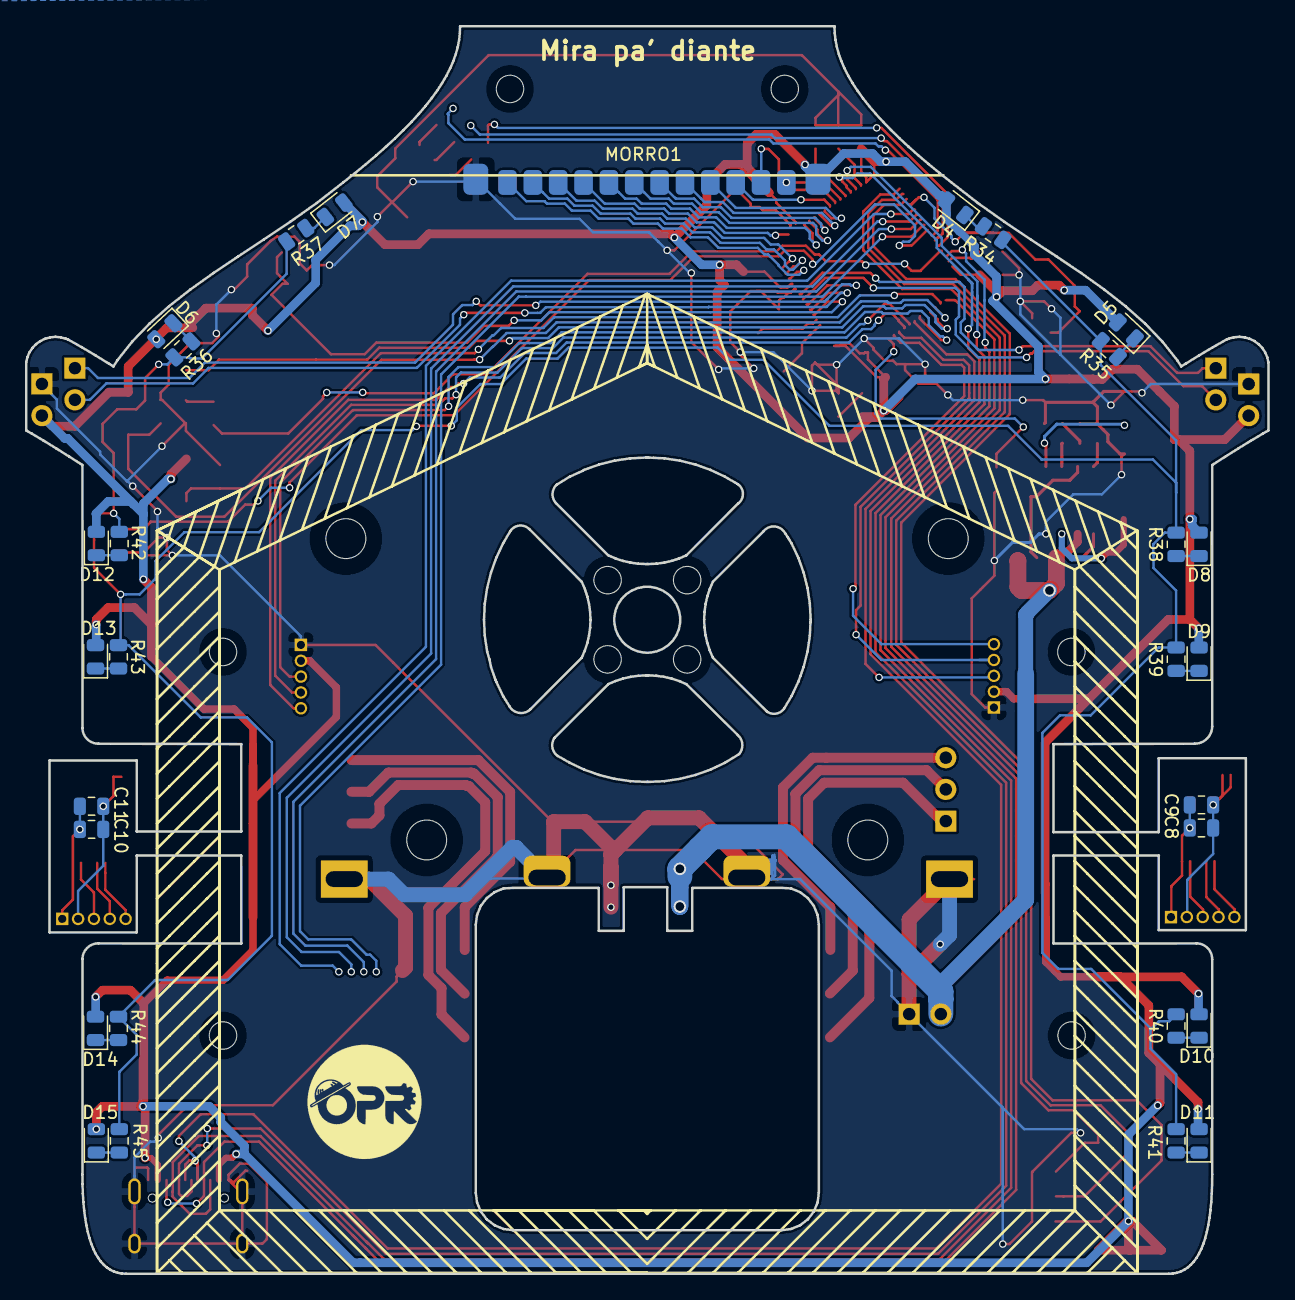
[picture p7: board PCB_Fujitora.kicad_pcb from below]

Board: 2 copper layers, 99.6 x 100.0 mm, 102 parts (29 on the bottom side), 93 nets.

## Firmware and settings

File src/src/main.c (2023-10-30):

#include "buttons.h"
#include "config.h"
#include "control.h"
#include "debug.h"
#include "delay.h"
#include "eeprom.h"
#include "encoders.h"
#include "leds.h"
#include "menu.h"
#include "motors.h"
#include "robotracer.h"
#include "sensors.h"
#include "setup.h"
#include "usart.h"

static bool use_btn_start = false;
static uint32_t millis_iniciado = 0;

void sys_tick_handler(void) {
  clock_tick();
  if (!is_esc_inited()) {
    init_esc();
  }
  update_encoder_readings();
  if (is_competicion_iniciada()) {
    update_log();
  }
}

/*
- [M] Encender robot
- [A] Cargar valores de EEPROM (sensores y menú) y asignarlos a sus variables correspondientes
- [M] Menú. Configurar/Comprobar velocidad y succión (estarán pre-cargados los valores confirmados anteriormente) y confirmar con BTN_START
- [M] Modo calibración.
- - [A] Si ya existen valores de calibración, se propone reutilizarlos (led rojo menu ON)
- - [M] Confirmar si usar valores de calibración existentes (led rojo menu ON) o calibrar de nuevo (led rojo menu OFF)
- - [A] Validar calibración de sensores (led rojo menu ON) & encoders al poner el robot en pista (todos sensores blanco)
- - [M?] Calibrar sensores (led rojo menu OFF) & comprobar encoders
- - [A/M] Si todo correcto, se muestra RGB verde por 1 segundo y se autoconfirma. En caso contrario, se queda en rojo y se confirma manual
- [A] Actualizar valores de EEPROM con calibración y menú
- [M] Modo menu again
- [M] Iniciar competición
*/

int main(void) {
  setup();
  eeprom_load();

  do {
    check_menu_button();
  } while (in_debug_mode() || !get_start_btn());
  do {
    reset_menu_mode();
    set_RGB_color(0, 0, 0);
  } while (get_start_btn());

  calibrate_sensors();

  eeprom_save();

  use_btn_start = get_swtich_3();
  millis_iniciado = 0;
  while (1) {
    if (!is_competicion_iniciada()) {
      if (get_millis_emergency_stop() != 0 && get_clock_ticks() - get_millis_emergency_stop() > MILLIS_STOP_FAN) {
        reset_millis_emergency_stop();
        set_fan_speed(0);
      }
      check_menu_button();
      if (!in_debug_mode()) {
        if ((use_btn_start && get_start_btn()) || (!use_btn_start && get_swtich_3())) {
          reset_menu_mode();
          set_status_led(false);
          while (get_start_btn()) {
            set_RGB_color(255, 0, 0);
          }
          uint32_t millisInicio = get_clock_ticks();
          uint16_t millisPasados = 5;
          while (get_clock_ticks() < (millisInicio + get_start_millis())) {
            millisPasados = get_clock_ticks() - millisInicio;
            uint8_t r = 0, g = 0;
            r = map(millisPasados, 0, get_start_millis(), 255, 0);
            g = map(millisPasados, 0, 1000, 0, 255);
            set_RGB_color(r, g, 0);
            if ((millisPasados > get_start_millis() * 0.75 || get_start_millis() == 0) && get_base_fan_speed() > 0) {
              set_fan_speed(get_base_fan_speed() * 0.75);
            }
          }
          set_competicion_iniciada(true);
          millis_iniciado = get_clock_ticks();
          set_RGB_color(0, 0, 0);
          set_ideal_motors_speed(get_base_speed());
          set_ideal_motors_ms_speed(get_base_ms_speed());
          set_acceleration_mss(get_base_acceleration_mss());
          set_deceleration_mss(get_base_deceleration_mss());
          set_ideal_fan_speed(get_base_fan_speed());
          set_fan_speed(get_base_fan_speed());
          if (get_config_track() == CONFIG_TRACK_ROBOTRACER) {
            robotracer_set_turn_speed(get_base_ms_speed());
            robotracer_set_straight_speed(get_robotracer_straight_ms_speed());
            robotracer_set_acceleration_mss(get_base_acceleration_mss());
            robotracer_set_deceleration_mss(get_base_deceleration_mss());
            robotracer_set_turn_acceleration_mss(get_base_turn_acceleration_mss());
            set_fans_speed(35, 35);
          }
          resume_pid_speed_timer();
        }
      }
    } else {

      if ((get_config_run() == CONFIG_RUN_DEBUG && get_clock_ticks() - millis_iniciado > 5000) || !get_swtich_3()) {
        emergency_stop();
      }
      // if (last_micrometers_r == 0 || last_micrometers_l == 0 || abs(last_micrometers_r - get_encoder_right_micrometers()) >= 10000 || abs(last_micrometers_l - get_encoder_left_micrometers()) >= 10000) {
      // last_micrometers_r = get_encoder_right_micrometers();
      // last_micrometers_l = get_encoder_left_micrometers();
      // printf("%ld\t%ld\n", get_encoder_x_position(), get_encoder_y_position());
      // delay(1);
      // }

      /* if (get_start_btn()) {
        set_ideal_motors_ms_speed(0.0);
        delay(100);
      }
      if (get_menu_down_btn()) {
        set_ideal_motors_ms_speed(1.0);
        delay(100);
      }
      if (get_menu_up_btn()) {
        set_ideal_motors_ms_speed(3.0);
        delay(100);
      }
      if (get_menu_mode_btn()) {
        set_ideal_motors_ms_speed(2.0);
        delay(100);
      }*/

      /*if (get_menu_down_btn()) {
        left_mark();
        delay(500);
      }

      if (get_menu_up_btn()) {
        right_mark();
        delay(500);
      }*/
      // check_sector_radius();
      // delay(1);
      // debug_accel();
      // printf("%ld (%.2f - %.2f)\n", get_sensor_line_position(), get_encoder_left_speed(), get_encoder_right_speed());

      //   uint32_t data_to_write[] = {2500, 250, 25, 5};
      //   uint32_t data_readback[] = {0, 0, 0, 0};
      // while (1) {

      //   if (get_start_btn()) {
      //     while (get_start_btn()) {
      //     }
      //     set_status_led(true);
      //     eeprom_clear();
      //     set_status_led(false);
      //   }

      //   // Write data to the emulated EEPROM
      //   if (get_menu_up_btn()) {
      //     while (get_menu_up_btn()) {
      //     }
      //     set_status_led(true);
      //     eeprom_set_data(4, (uint32_t[]){3215, 125, 98, 138}, 4);
      //     eeprom_save();
      //     set_status_led(false);
      //   }

      //   if (get_menu_down_btn()) {
      //     while (get_menu_down_btn()) {
      //     }
      //     set_status_led(true);
      //     eeprom_set_data(0, (uint32_t[]){2500, 250, 25, 5}, 4);
      //     eeprom_save();
      //     set_status_led(false);
      //   }

      //   // Read data from the emulated EEPROM
      //   if (get_menu_mode_btn()) {
      //     while (get_menu_mode_btn()) {
      //     }
      //     uint32_t *data = eeprom_get_data();
      //     for (uint8_t i = 0; i < DATA_LENGTH; i++) {
      //       printf("%ld ", data[i]);
      //     }
      //     printf(" -> ");
      //     eeprom_load();
      //     for (uint8_t i = 0; i < DATA_LENGTH; i++) {
      //       printf("%ld ", data[i]);
      //     }
      //     printf("\n");
      //   }
      // }
    }
  }
}

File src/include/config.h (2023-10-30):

#ifndef __CONFIG_H
#define __CONFIG_H

#include "buttons.h"

#include <stdio.h>

#define SYSCLK_FREQUENCY_HZ 168000000
#define SYSTICK_FREQUENCY_HZ 1000
#define MICROMETERS_PER_METER 1000000
#define MICROSECONDS_PER_SECOND 1000000
#define PI 3.1415

#define MS_CALIBRACION_LINEA 5000
#define LECTURA_MAXIMO_SENSORES_LINEA 4096
#define LECTURA_MINIMO_SENSORES_LINEA 0

#define LEDS_MAX_PWM 1024
#define MOTORES_MAX_PWM 1024

// LINEFOLLOWER
// #define KP 0.02
// #define KI 0
// #define KD 1.25

// ROBOTRACER
#define KP 0.045 // 0.04 //0.02 //0.022
#define KI 0
#define KD 2.85 // 2.5 //0.4 //0.25

#define KP_MS 10.0
#define KI_MS 1.2
#define KD_MS 20.0

#define MILLIS_INICIO_DEBUG 2000
#define MILLIS_INICIO_RUN 5000
#define MILLIS_STOP_FAN 1500
#define TIEMPO_SIN_PISTA 150

#define MICROMETERS_PER_TICK_ROBOTRACER 78.3699
#define MICROMETERS_PER_TICK_LINEFOLLOWER 19.5925
#define WHEELS_SEPARATION 0.1169

#define MIN_SPEED_PERCENT 5
#define MAX_ACCEL_PERCENT 45.0
#define MIN_ACCEL_MS2 3.0
#define MAX_ACCEL_MS2 8.0
#define MAX_BREAK_MS2 10.0

#define CONFIG_RUN_RACE 1
#define CONFIG_RUN_DEBUG 0

#define CONFIG_SPEED_MS 1
#define CONFIG_SPEED_PWM 0

#define CONFIG_TRACK_ROBOTRACER 1
#define CONFIG_TRACK_LINEFOLLOWER 0

#define CONFIG_ROBOT_ROBOTRACER 1
#define CONFIG_ROBOT_LINEFOLLOWER 0

#define CONFIG_TRACK_TYPE_ENHANCED 1
#define CONFIG_TRACK_TYPE_NORMAL 0

#define CONFIG_LINE_WHITE 1
#define CONFIG_LINE_BLACK 0

void set_all_configs(void);
uint16_t get_config_run(void);
uint16_t get_config_speed(void);
uint16_t get_config_track(void);
uint16_t get_config_track_type(void);
uint16_t get_config_robot(void);
uint16_t get_config_line(void);
float get_micrometers_per_tick(void);

uint16_t get_offtrack_time(void);
uint16_t get_start_millis(void);

#endif

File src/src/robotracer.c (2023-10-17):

#include "robotracer.h"

static float acceleration_mss = MAX_ACCEL_MS2;
static float deceleration_mss = MAX_BREAK_MS2;
static float turn_speed = 1.25f;
static float straight_speed = 4.0f;
static float turn_acceleration_mss = 0.8038f;

static bool left_mark = false;
static bool right_mark = false;

bool map_iniciado = false;
bool map_realizado = false;
bool vuelta_finalizada = false;

bool run_iniciado = false;
bool run_realizado = false;
uint16_t map_sector_actual = 0;
uint16_t run_sector_actual = 0;

uint32_t last_left_ticks = 0;
uint32_t last_right_ticks = 0;

uint32_t last_check_sector_left_ticks = 0;
uint32_t last_check_sector_right_ticks = 0;

#define MAX_CURRENT_SECTOR_SAMPLES 1000
uint8_t current_sector_radius_samples = 0;
float current_sector_radius[MAX_CURRENT_SECTOR_SAMPLES];
float current_sector_radius_filter = 0;

uint32_t pista_sectores[1000];
uint32_t pista_sectores_run[1000];
float sectores_tipos[1000];

static void reset_encoders(void) {
  last_left_ticks = get_encoder_left_total_ticks();
  last_right_ticks = get_encoder_right_total_ticks();
  last_check_sector_left_ticks = get_encoder_left_total_ticks();
  last_check_sector_right_ticks = get_encoder_right_total_ticks();
}

static void init_map(void) {
  printf("Mapeo iniciado\n");
  set_status_led(true);
  reset_encoders();
  map_iniciado = true;
  set_fans_speed(35, 35);
}

static void end_map(void) {
  printf("Mapeo finalizado\n");
  set_status_led(false);
  map_realizado = true;

  // for (int i = 0; i < vector_size(pista_sectores); i++) {
  for (int i = 0; i < map_sector_actual; i++) {
    printf("%ld (r=%.2fcm - l=%.2fm)\n", pista_sectores[i], sectores_tipos[i], pista_sectores[i] * get_micrometers_per_tick() / MICROMETERS_PER_METER);
  }

  reset_encoders();
}

static void robotracer_map_last_sector(void) {
  uint32_t avg_ticks_sector = (max_likelihood_counter_diff(get_encoder_left_total_ticks(), last_left_ticks) + max_likelihood_counter_diff(get_encoder_right_total_ticks(), last_right_ticks)) / 2;

  float left_distance_meters = max_likelihood_counter_diff(get_encoder_left_total_ticks(), last_left_ticks) * get_micrometers_per_tick() / MICROMETERS_PER_METER;
  float right_distance_meters = max_likelihood_counter_diff(get_encoder_right_total_ticks(), last_right_ticks) * get_micrometers_per_tick() / MICROMETERS_PER_METER;
  float radius = (WHEELS_SEPARATION / 2.0f) * (left_distance_meters + right_distance_meters) / (left_distance_meters - right_distance_meters) * 100;
  if (isnan(radius) || isinf(radius) || abs(radius) > 100) {
    radius = 0;
  }

  float avg_distance_meters = avg_ticks_sector * get_micrometers_per_tick() / MICROMETERS_PER_METER;
  if (avg_distance_meters > 0.1 || (radius > 0.0f && radius < 100.0f)) {

    // vector_add(&sectores_tipos, float) = radius;
    // vector_add(&pista_sectores, uint32_t) = avg_ticks_sector;
    sectores_tipos[map_sector_actual] = radius;
    pista_sectores[map_sector_actual] = avg_ticks_sector;
    map_sector_actual++;

    reset_encoders();
    current_sector_radius_samples = 0;
  }
}

static float calc_run_max_turn_speed(float radius) {
  if (radius == 0) {
    return straight_speed;
  }
  // u = 2.74?
  // float a_max = 0.8038f;
  float max_turn_speed = 3.6f * sqrt(turn_acceleration_mss * abs(radius) / 100.0f);

  // if (ticks_lenght <= 0.35 * MICROMETERS_PER_METER / get_micrometers_per_tick() && abs(max_turn_speed - get_encoder_avg_speed()) > 2) {
  //   max_turn_speed = max_turn_speed / 2;
  // }
  // printf("%.4f=3.6*sqrt(%.4f*%.4f)\n", max_turn_speed, a_max, radius / 100.0f);
  if (max_turn_speed < turn_speed || radius < 20) {
    max_turn_speed = turn_speed;
  }
  return max_turn_speed;
}

static void set_ideal_speed_sector_actual(void) {
  if (abs(sectores_tipos[run_sector_actual]) < 5) {
    set_ideal_motors_ms_speed(straight_speed);
    set_fans_speed(40, 40);
    set_status_led(false);
    set_RGB_color(0, 255, 0);
  } else {
    // set_ideal_motors_ms_speed(turn_speed);
    set_ideal_motors_ms_speed(calc_run_max_turn_speed(sectores_tipos[run_sector_actual]));
    set_fans_speed(75, 75);
    set_status_led(true);
    set_RGB_color(0, 0, 255);
  }
}

static void init_run(void) {
  run_iniciado = true;
  run_realizado = false;
  run_sector_actual = 0;
  set_fans_speed(35, 35);
  reset_encoders();
  set_ideal_speed_sector_actual();
}

static void end_run(void) {
  run_realizado = true;
  reset_encoders();
}

static void run_next_sector(void) {
  uint32_t avg_ticks_sector = (max_likelihood_counter_diff(get_encoder_left_total_ticks(), last_left_ticks) + max_likelihood_counter_diff(get_encoder_right_total_ticks(), last_right_ticks)) / 2;
  if (avg_ticks_sector > pista_sectores_run[run_sector_actual] * 0.80f) {
    reset_encoders();
    run_sector_actual++;
    set_ideal_speed_sector_actual();
  }
}

static void check_next_sector_radius(void) {
  if (map_realizado && run_iniciado) {

    float avg_speed = get_encoder_avg_speed();

    uint16_t sector_check_radius = run_sector_actual + 1;
    while (sectores_tipos[sector_check_radius] == 0 && sector_check_radius < map_sector_actual) {
      sector_check_radius++;
    }
    float next_turn_radius = sectores_tipos[sector_check_radius];

    float next_turn_speed = (sector_check_radius < map_sector_actual) ? calc_run_max_turn_speed(next_turn_radius) : turn_speed;
    if (avg_speed > next_turn_speed) {
      float time_to_stop = (next_turn_speed - get_encoder_avg_speed()) / -deceleration_mss;
      float meters_to_stop = (get_encoder_avg_speed() * time_to_stop) - (0.5 * deceleration_mss * (time_to_stop * time_to_stop));
      meters_to_stop += (avg_speed - next_turn_speed) * 0.125; // Añade una distancia de seguridad a la frenada
      uint32_t ticks_to_stop = (meters_to_stop)*MICROMETERS_PER_METER / get_micrometers_per_tick();
      int32_t avg_ticks_sector = (max_likelihood_counter_diff(get_encoder_left_total_ticks(), last_left_ticks) + max_likelihood_counter_diff(get_encoder_right_total_ticks(), last_right_ticks)) / 2;

      uint32_t ticks_recto = (pista_sectores_run[run_sector_actual] - avg_ticks_sector);
      uint16_t sector_check = run_sector_actual + 1;
      while (sector_check < map_sector_actual && sectores_tipos[sector_check] == 0) {
        ticks_recto += pista_sectores_run[sector_check];
        sector_check++;
      }
      if (ticks_recto <= ticks_to_stop) {
        set_ideal_motors_ms_speed(next_turn_speed);
        set_RGB_color(255, 0, 0);
        set_fans_speed(50, 50);
        set_status_led(true);
      }
    }
  }
}
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

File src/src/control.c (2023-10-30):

#include "control.h"

static float velocidad = 0;
static int32_t velocidadIdeal = 0;
static float velocidadIdealMs = 0.0;
static float velocidadObjetivoMs = 0.0;
static float accelerationMss = 0.0;
static float decelerationMss = 0.0;
static int32_t velocidadVentiladorIdeal = 0;
static bool fullVelocidadVentilador = false;
static bool competicionIniciada = false;
static uint32_t competicionIniciadaMillis = 0;
static volatile float correccion_velocidad = 0;
static volatile float error_anterior = 0;
static volatile float suma_error_ms = 0;
static volatile float error_anterior_ms = 0;

static uint32_t resume_speed_ms = 0;

/**
 * @brief Calcula la corrección de posición en línea mediante PID
 * 
 * @param posicion Posición actual actual del robot sobre la línea
 * 
 * @return float Corrección aplicada sobre la velocidad
 */

float calc_pid_correction(int32_t posicion) {
  float p = 0;
  float i = 0;
  float d = 0;
  int32_t error = 0 - posicion;

  p = KP * error;
  d = KD * (error - error_anterior);
  error_anterior = error;

  return p + i + d;
}

/**
 * @brief Calcula la corrección de la velocidad en m/s mediante PID
 * 
 * @param velocidadActualMs Velocidad actual en m/s obtenida de los encoders
 * 
 * @return float Velocidad aplicada a los motores en %
 */

float calc_ms_pid_correction(float velocidadActualMs) {
  float p = 0;
  float i = 0;
  float d = 0;
  float error_ms = velocidadObjetivoMs - velocidadActualMs;

  if (velocidadObjetivoMs <= 1.0 && velocidadActualMs < velocidadIdealMs && velocidadIdealMs > 0) {
    if (KI_MS * suma_error_ms < 20.0) {
      suma_error_ms += error_ms;
    } else {
    }
  } else {
    suma_error_ms += error_ms;
  }
  // p = KP_MS * error_ms;
  i = KI_MS * suma_error_ms;
  // d = KD_MS * (error_ms - error_anterior_ms);
  error_anterior_ms = error_ms;

  return p + i + d;
}

/**
 * @brief Comprueba si el robot está en funcionamiento
 * 
 * @return bool 
 */

bool is_competicion_iniciada(void) {
  return competicionIniciada;
}

/**
 * @brief Establece el estado actual del robot
 * 
 * @param state Estado actual del robot
 */

void set_competicion_iniciada(bool state) {
  competicionIniciada = state;
  if (state) {
    competicionIniciadaMillis = get_clock_ticks();
  } else {
    competicionIniciadaMillis = 0;
  }
}

uint32_t get_competicion_iniciada_millis(void) {
  return competicionIniciadaMillis;
}

/**
 * @brief Función ISR del Timer5 encargada del control de posición, velocidad y mapeo de pista en caso de robotracer
 * 
 */
void pid_speed_timer_custom_isr(void) {
  calc_sensor_line_position();
  correccion_velocidad = calc_pid_correction(get_sensor_line_position());

  if (get_config_track() == CONFIG_TRACK_ROBOTRACER) {
    robotracer_loop_flow();
  }

  if (is_competicion_iniciada()) {
    if (get_config_speed() == CONFIG_SPEED_MS) {
      if (velocidadIdealMs > 0 || velocidadObjetivoMs > 0 || velocidad > 0) {
        if (velocidadObjetivoMs < velocidadIdealMs) {
          if (velocidadObjetivoMs < 1 && velocidadIdealMs > 0) {
            velocidadObjetivoMs += MIN_ACCEL_MS2 / 1000.0;
          } else {
            velocidadObjetivoMs += accelerationMss / 1000.0;
          }
        } else if (velocidadObjetivoMs > velocidadIdealMs) {
          if (velocidadObjetivoMs < 1 && velocidadIdealMs > 0) {
            velocidadObjetivoMs -= MIN_ACCEL_MS2 / 1000.0;
          } else {
            velocidadObjetivoMs -= decelerationMss / 1000.0;
          }
        }
        if (velocidadIdealMs != velocidadObjetivoMs && abs(velocidadIdealMs * 100 - velocidadObjetivoMs * 100) < 2) {
          velocidadObjetivoMs = velocidadIdealMs;
        }
        if (get_encoder_avg_speed() > 0.25) {
          velocidad = MIN_SPEED_PERCENT + calc_ms_pid_correction(get_encoder_avg_speed());
          if (get_encoder_avg_speed() > 0.5) {
            fullVelocidadVentilador = true;
          }
        } else {
          velocidad = 22;
          suma_error_ms = 0;
        }
        if (velocidad > 100) {
          velocidad = 100;
        } else if (velocidad < 0) {
          suma_error_ms = 0;
          velocidad = 0;
        }
        // if (get_clock_ticks() % 20 == 0) {
        //   debug_accel();
        // }
      } else {
        velocidad = 0;
        set_motors_speed(0, 0);
        set_fans_speed(0, 0);
        return;
      }
    } else {
      if (velocidadIdeal > 0) {
        if (velocidad < velocidadIdeal) {
          if (velocidad < MIN_SPEED_PERCENT) {
            velocidad = 15;
          }
          float increment_percent = ((get_clock_ticks() - resume_speed_ms) / 1000.0) * MAX_ACCEL_PERCENT;
          velocidad = 15 + increment_percent;
        } else if (velocidad != velocidadIdeal) {
          velocidad = velocidadIdeal;
        }
        if (velocidad > 30) {
          fullVelocidadVentilador = true;
        }
      } else {
        velocidad = 0;
        set_motors_speed(0, 0);
        set_fans_speed(0, 0);
        return;
      }
    }

    float velI = velocidad - correccion_velocidad;
    float velD = velocidad + correccion_velocidad;

    if (velD < MIN_SPEED_PERCENT) {
      // velI += MIN_SPEED_PERCENT - velD;
      velD = MIN_SPEED_PERCENT;
    } else if (velD > 100) {
      // velI -= velD - 100;
      velD = 100;
    }
    if (velI < MIN_SPEED_PERCENT) {
      // velD += MIN_SPEED_PERCENT - velI;
      velI = MIN_SPEED_PERCENT;
    } else if (velI > 100) {
      // velD -= velI - 100;
      velI = 100;
    }
    set_motors_speed(velD, velI);
    if (get_config_track() == CONFIG_TRACK_LINEFOLLOWER) {
      set_fan_speed(fullVelocidadVentilador ? velocidadVentiladorIdeal : (velocidadVentiladorIdeal / 2));
    }

  } else {
    velocidad = 0;
    set_motors_speed(0, 0);
  }
}

/**
 * @brief Obtiene la corrección de la Velocidad mediante PID para tareas de depuración
 * 
 * @return float 
 */
float get_speed_correction(void) {
  return correccion_velocidad;
}

/**
 * @brief Establece la velocidad ideal de los motores desde configuración
 * 
 * @param v Velocidad en % de PWM
 */
void set_ideal_motors_speed(int32_t v) {
  velocidadIdeal = v;
}

/**
 * @brief Establece la velocidad ideal de los motores desde configuración
 * 
 * @param ms Velocidad en m/s
 */
void set_ideal_motors_ms_speed(float ms) {
  velocidadIdealMs = ms;
}

/**
 * @brief Establece la aceleración máxima al incrementar velocidad
 * 
 * @param mss Aceleración en m/s/s
 */
void set_acceleration_mss(float mss) {
  accelerationMss = mss;
}

/**
 * @brief Establece la aceleración máxima al reducir velocidad
 * 
 * @param mss Aceleración en m/s/s
 */
void set_deceleration_mss(float mss) {
  decelerationMss = mss;
}

/**
 * @brief Establece la velocidad del ventilador de succión / soplar
 * 
 * @param v Velocidad en % de PWM
 */
void set_ideal_fan_speed(int32_t v) {
  velocidadVentiladorIdeal = v;
}
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

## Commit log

2019-07-31 Añade ficheros de config y soporte para USART
2019-07-31 Añade gpio_mode_setup y pruebas de leds y botones
2019-07-31 Añade config de ADC1 y DMA2 para lect de sensores
2019-08-01 Añade configuración de PWM en TIM1 para LEDS
2019-08-01 Añade funciones de control de leds; Rainbow, Fade
2019-08-08 Mejora la gestión de los sensores
2019-08-08 Añade calibración y debug de pos (+ solve bugs)
    [debug.c, debug.h, leds.c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]
2019-08-09 Añade configuración de TIM8 para PWM ESC
2019-08-09 Añade iniciación de ESC "en segundo plano"
2019-08-09 Añade configuración de velocidad de motores en %
2019-08-09 Añade debug de motores
2019-08-09 Añade funciones de debug mediante switch
2019-08-09 Añade espera para calibración al inicio
2019-08-09 Soluciona error en cálculo de posición
    [debug.c, sensors.c]
2019-08-11 Añade config y base de timers de pid y velocidad
2019-08-11 Añade menu de configuración
2019-08-12 Añade calibración automática y alarma de umbrales
2019-08-12 Completa programa básico de siguelíneas #estable
2019-08-15 Añade gestión de marcas laterales
2019-08-15 Añade funciones de debug al inicio
2019-08-15 Añade comprobaciones de marcas laterales
2019-08-15 Añade compensación de vel inicial + menu bug fix
    [debug.c, motors.c]
2019-08-16 Añade detección de inicio y fin de vuelta
2019-08-17 Ajusta PID para curvas R10
2019-08-17 Ajusta compensación de velocidad por PID
2019-08-17 Comenta inicio-fin de vuelta
2019-08-17 Pasa la velocidad, corrección de PID y map a float · Añade aceleraciones
2019-08-17 Añade alarma de calibración de marca
2019-08-19 Añade control de ventiladores
2019-08-19 Pasa la función constrain a float
2019-08-19 Ajusta el rango de velocidades de motores
2019-08-24 Añade configuración de encoders
2019-08-25 Separa los valores de config de menú por modos
2019-08-30 Actualiza la placa de desarrollo
2019-08-30 Añade soporte de ventiladores superiores
2019-09-14 Añade PCB principal y sensores; Kicad & gerbers
    [PCB_Fujitora-B.Cu.gbl, PCB_Fujitora-B.Mask.gbs, PCB_Fujitora-B.SilkS.gbo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]
2019-09-14 Añade img de presentación
2019-09-23 Añade configuración de encoders e inicio de mapeo
2019-09-28 Añade gestión inicial de configs mediante Switches
2019-09-28 Closes #1, closes #2; Mejora el menú y el debug.
2019-09-29 Actualiza el debugger por defecto de la placa
2019-09-29 Pasa el cálculo del PID y Vel a 1ms; Closes #3
2019-09-29 Corrige debug de posición en pista
    [debug.c]
2019-10-14 Añade filtro de marcas secundarias; Closes #6
2019-10-19 Añade debug de posición y corrección
2019-10-26 Añade control de velocidad por m/s con encoders
2019-10-31 Mejora control de aceleraciones usando m/s
2019-10-31 Limita la aceleración inicial al arrancar
2019-10-31 Soluciona bug de reiniciar carrera al pierde línea
    [sensors.c]
2019-10-31 Mejora el control de aceleración en arranque
2019-10-31 Añade logs de aceleración en comentarios
2019-11-02 Mejora el debug de sensores imprimiendo en orden
2019-11-02 Mejora acelerción y añade función de debug
2019-11-03 Añade funciones de prueba
2019-11-07 Ajusta el tiempo de inicio en función de RUN/DEBUG
2019-11-07 Corrige error de parada automática al perder línea
    [sensors.c]
2019-11-11 Actualiza % de velocidad en el menú
2019-11-15 Añade cambio de morros y actualiza calibración
2019-11-17 Soluciona bug de pos de línea en robotracer
    [sensors.c]
2019-11-17 Añde PID de morro corto y ÑAPA para R10 robotracer
2019-11-18 Añade config estable (1.25m/s) para morro corto
2019-11-19 Mejora el PID de morro corto
2019-11-19 Modifica funciones y crea filtro de radio de curva
2019-11-19 Añade filtro de intersec. a marca de inicio-fin
2019-11-25 Añade config "estable" map-run a 1.25m/s-4 m/s: · Permite volver a realizar carrera · No calibra morro largo para evitar bugs de comprobación de sensores · Ajusta MAX_ACCEL_MS2 y MAX_BREAK_MS2 · Solu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
    [config.h, control.c, robotracer.c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]
2019-11-26 Añade control de ventiladores en resolución
2019-11-26 Mejora el fin de sector sin marca y el reinicio
2019-11-26 Añade cambio de velocidad mediante menú
2020-02-12 Añade comentarios a buttons.c y control.c
2020-09-14 Añade algo de documentación en ciertas funciones
2020-09-14 Añade filtro de paso bajo a los botones
2020-09-16 Saca las funciones de robotracer del loop de PID
2020-10-26 Actualiza ticks de encoders
2022-10-06 Añade configuración específica de plataforma
2022-10-06 Añade configuraciones independientes de pista, robot y línea
2022-10-11 Añade menú de configuración de morro
2022-10-13 Añade configuración de encoders en función de robot
2022-10-13 Ajusta los valores de velocidad a algo menos optimista
2022-10-17 Ajusta constantes PID de morro corto
2022-10-27 Añade cambio de morro en calibración y configuración de tipo de pista
2023-01-31 Actualiza velocidad de ventiladores de debug a 80
2023-01-31 Añade inicio sin calibrar y parada de emergecia y debug
2023-01-31 Completa el proceso de inicio sin calibración
2023-02-02 Corrige gambada de parada de emergencia
    [main.c]
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2023-02-06 Mejora el proceso de inicio y ajustes varios
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2023-02-07 Actualiza antiflex y añade separador de la falda
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2023-02-24 Elimina menú de tipo de morro y mejora el uso de calibración guardada
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2023-04-29 Limpia codigo de doble morro y ajusta los includes propios para usar comillas dobles
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2023-04-30 Añade PCB de morro de 16 sensores y actualiza README
    [Solo_morro2-B_Cu.gbl, Solo_morro2-B_Mask.gbs, Solo_morro2-B_Silkscreen.gbo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]
2023-10-17 Actualiza versión de platform y limpia errores y warnings
    [buttons.c, config.c, control.c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]
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2023-10-20 Añade gestión de EEPROM básica · custom_stm32f405rgt6.json y memory_map.id no son estrictamente necesarios
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2023-10-21 Añade feedback por led cuando se guarda EEPROM
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2023-10-26 Corrige mini fallos de eeprom
    [eeprom.h]
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2023-10-30 Corrige control de ventilador después de parada
    [config.h, main.c, sensors.c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]
2024-04-24 Comenta el botón de menú abajo y añade filtro por software al pin del módulo de inicio
2024-04-24 Mejora el menú para volver al inicio de la configuración al pulsar arriba en el último valor
